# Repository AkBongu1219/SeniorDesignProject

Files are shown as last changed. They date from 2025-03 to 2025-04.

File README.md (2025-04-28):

# Domus Smart Home

## Edge-Controlled Smart Home Ecosystem Integrating Energy Management, Security, and Privacy-Focused Automation

---

## Project Overview

**Domus** is a unified smart home control and security system, designed to overcome the fragmentation in traditional home automation solutions. Built on the Raspberry Pi platform and supported by a network of ESP32-based sensor nodes, Domus integrates:

- Environmental Monitoring (Air Quality, Temperature, Humidity, Pressure)
- Motion Detection with automatic camera activation
- Vision-Based Surveillance (Object Detection & Face Recognition)
- Energy Monitoring and Smart Plug Control
- Edge-Deployed LLM Integration for natural language queries and interaction

The system operates entirely without cloud dependency, ensuring local data ownership, enhanced privacy, and low-latency control. Domus leverages a hardware-software co-design approach, combining industrial IoT components, machine learning models, and robust system architecture for a responsive, secure, and modular smart home experience.

---

## Problem Statement

Current smart home solutions often rely on fragmented, cloud-dependent ecosystems with limited interoperability between security, environmental sensing, and energy control. Domus addresses this gap by offering an all-encompassing, modular smart home ecosystem deployed at the edge. It harnesses state-of-the-art technologies like on-device Large Language Models (LLMs), lightweight computer vision frameworks (MobileNet SSD, dlib), and real-time data processing to ensure:

- Robust Security: Theft detection through face recognition and motion-triggered camera surveillance.
- Energy Awareness: Live and historical energy consumption monitoring with anomaly alerts.
- Seamless Control: A centralized, app-based interface for device management and status queries.
- Privacy and Data Ownership: No cloud dependency; all computation happens locally.

---

## System Architecture

The architecture consists of a central Raspberry Pi 5 node, which communicates with distributed ESP32-based Domus sensor units, a Raspberry Pi 4 vision module, and the Domus iOS mobile application.

**System Diagram Placeholder:**  
*(Insert system architecture diagram here: ./assets/system_architecture.png)*

---

## Current Status

The Domus Smart Home System is fully developed, tested, and available for installation. All hardware and software components are complete. User manual, test plans, and setup guides are provided within the repository to ensure easy deployment by future users or developers.

---

## Future Work / Recommendations

While the Domus Smart Home System is fully functional, several areas offer opportunities for future improvement or extension:

- **Cloud-Optional Remote Access:** Implement an optional secure cloud relay for remote access when away from the local network, while maintaining local-first architecture.
- **Custom Alert Configuration:** Allow users to define custom alert rules and thresholds directly through the mobile app interface.
- **Multi-User Role Management:** Extend app functionality to support multiple user roles (admin, guest, etc.) with customizable permissions.
- **Enhanced LLM Query Handling:** Improve natural language query robustness by expanding prompt engineering techniques and fine-tuning on home automation-specific datasets.
- **Automatic Sensor Calibration:** Integrate a calibration routine for environmental and motion sensors during initial setup or periodic operation.
- **Additional Smart Appliance Integration:** Extend support to other smart plugs, lights, and appliances through MQTT or Home Assistant-compatible APIs.
- **Battery Backup Option for Sensor Nodes:** Add battery backup to ESP32 sensor nodes for continued operation during power outages.

These enhancements would increase flexibility, scalability, and robustness for long-term deployments and broader user scenarios.

---

## Things to Watch Out For

- Device Pairing Requires Manual Wi-Fi Setup: Ensure ESP32 devices are properly configured with Wi-Fi credentials via AP mode before pairing.
- Startup Sequence: Always power on the Raspberry Pi 5 central node before powering up peripheral ESP32 devices to ensure successful check-in.
- Surveillance Module Dependency: The Raspberry Pi 4 must be active for facial recognition and object detection features to work properly.
- Energy Monitoring Limitations: Ensure appliances connected to the Domus Power Plug do not exceed rated load (15A/1800W).
- Wi-Fi Reliability: The system assumes stable Wi-Fi coverage across all device locations.
- AI Camera Positioning: Place the camera near the main entrance or high-traffic zones for effective motion-triggered surveillance.
- LLM Query Limitations: GPT-based natural language queries require structured prompts; misuse or malformed queries may lead to irrelevant responses.
- Sensor Calibration: Initial placement and testing are recommended to avoid false positives from motion or environmental sensors.

---

## Getting Started (Quick-Start Checklist)

1. Hardware Setup:
   - Power on the Raspberry Pi 5 (central node) and Raspberry Pi 4 (vision module).
   - Connect ESP32 sensors (motion, BME688) to wall sockets and ensure they are within Wi-Fi range.
   - Place the AI camera near desired surveillance areas.
   - Connect the Kasa Smart Plug to a power source and the local network.
   - Refer to `README_HARDWARE.md` for detailed instructions.

2. Software Setup:
   - Clone this repository to your local machine or Raspberry Pi:
     ```bash
     git clone https://github.com/AkBongu1219/SeniorDesignProject
     ```
   - For Domus device users: Directly deploy the Domus iOS app by following setup instructions on `README_SOFTWARE.md`.
   - For manual setup, refer to `README_SOFTWARE.md`to setup backend.  
   - Log into the app using Google login.
   - Pair sensors via the "Devices" screen in the app.

3. First Test Run:
   - Confirm device check-ins on the backend dashboard or through the app.
   - Verify live data streams on the app's Home, Energy, and Surveillance screens.
   - Test LLM integration by querying system status via the app's assistant interface.

4. Need Help?
   - Refer to the User Manual (`User_Manual.pdf`) in this repository.
   - For common errors and troubleshooting, see the "Getting Help" section of the User Manual.
   - Contact Team 27 (emails listed below).

---

## Contributors (Team 27)

| Name | Role | Email |
|---|---|---|
| Venkata Sai Sreeram Andra | System Integration, ML Pipelines | vssa8989@bu.edu |
| Anirudh Singh | Backend Development, API Integration| ansingh@bu.edu |
| Vansh Bhatia | Hardware Design, Sensor Integration | vansh@bu.edu |
| Akhil Bongu | Vision Module, Object Detection | akbongu@bu.edu |

---

*End of README.md*

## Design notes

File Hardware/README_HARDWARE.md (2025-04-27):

# Domus Smart Home — Hardware Documentation

**EC464 Senior Design Project**  
**Boston University, Team 27**

---

## 1. Introduction / Overview of Hardware System

The Domus Smart Home system employs a network of hardware components to enable environmental sensing, energy monitoring, and vision-based security. Built on an edge-deployed architecture, the system ensures enhanced privacy and low-latency performance without cloud dependency.

### Key Hardware Components:
- ESP32 Microcontrollers: Motion detection and air quality sensing.
- Raspberry Pi 5: Central control unit.
- Raspberry Pi 4: Dedicated video processing (vision module).
- TP-Link KP115 Smart Plug: Real-time energy tracking and appliance control.
- IMX500 AI-Enabled Camera Module: Object detection and facial recognition.

All devices communicate over a local Wi-Fi network, providing seamless integration and reliable modular deployment.

---

## 2. System Diagram / Hardware Schematic

The system architecture, including sensor nodes, camera module, and smart plug integration, is illustrated below:

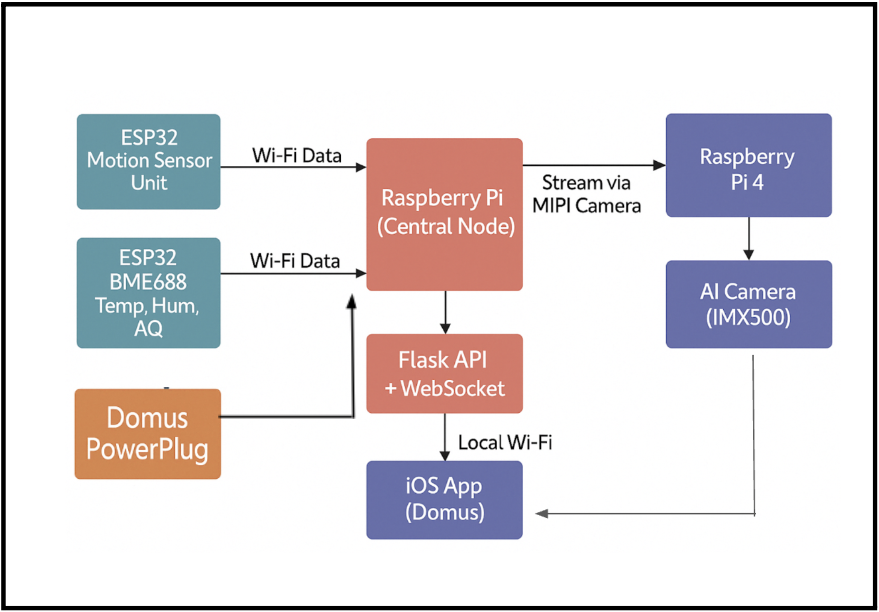
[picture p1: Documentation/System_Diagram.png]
Domus System Hardware Schematic


---

## 3. Photos of Physical Hardware Modules

### Domus Hardware Modules

#### Domus EnvironSensor Module  
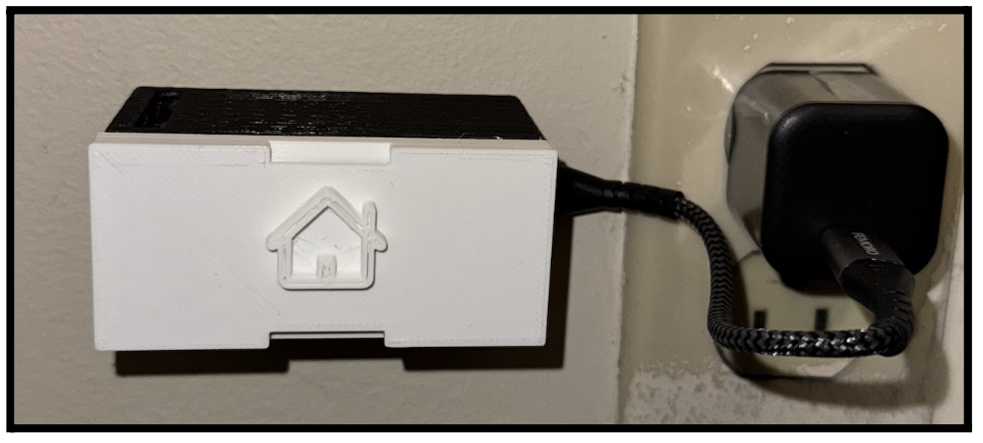
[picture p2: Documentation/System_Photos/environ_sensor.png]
Domus EnvironSensor


#### Domus Vision Module  
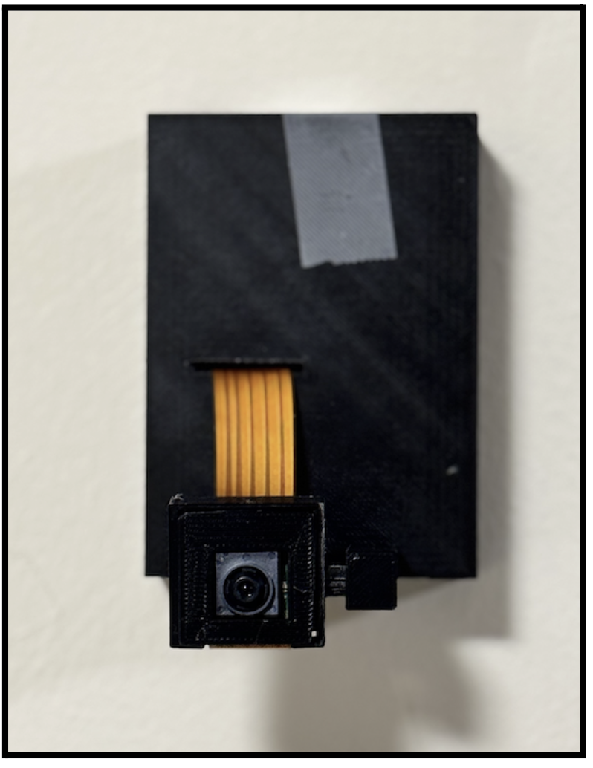
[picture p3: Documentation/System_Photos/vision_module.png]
Domus Vision Module


#### Domus Power Plug  
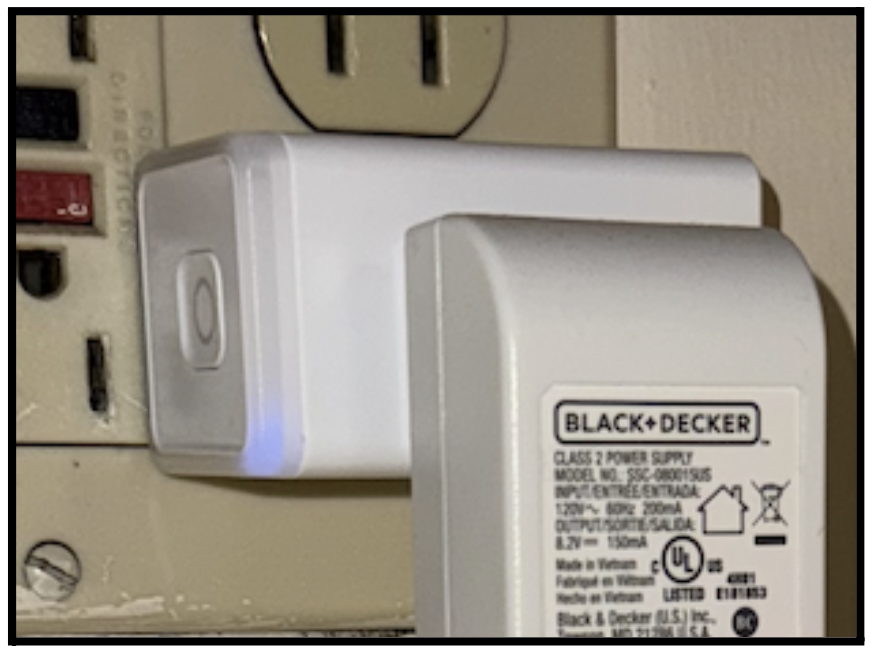
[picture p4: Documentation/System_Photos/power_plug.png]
Domus Power Plug


#### Domus Central Hub (Raspberry Pi 5)  
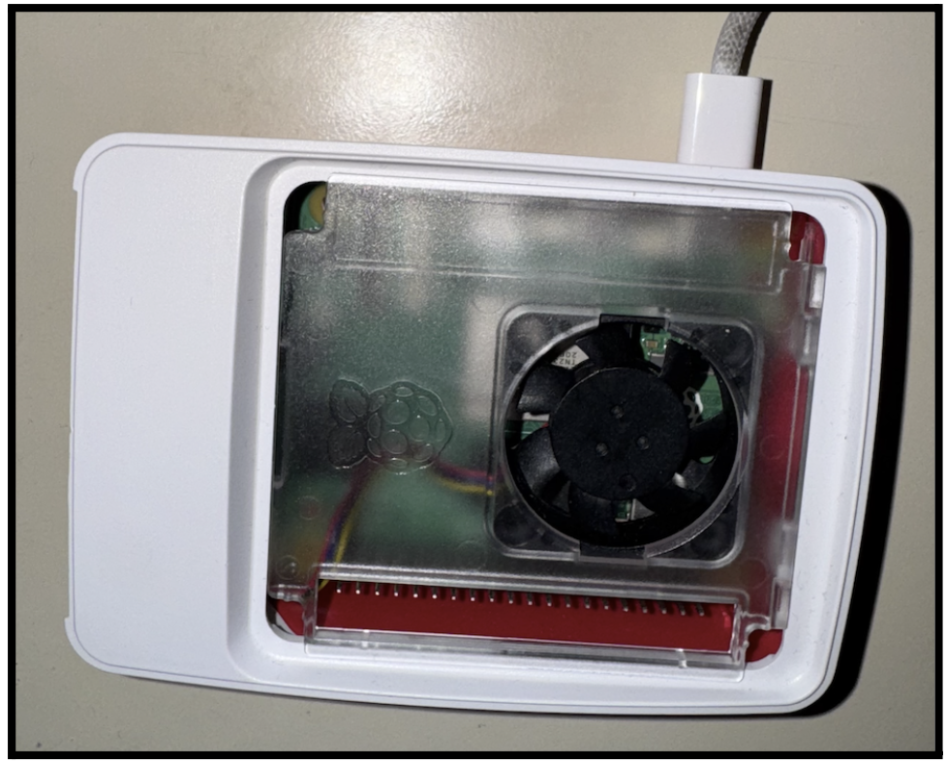
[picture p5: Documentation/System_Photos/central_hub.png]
Domus Central Hub


#### Domus Motion Sensor (HC-SR501)  
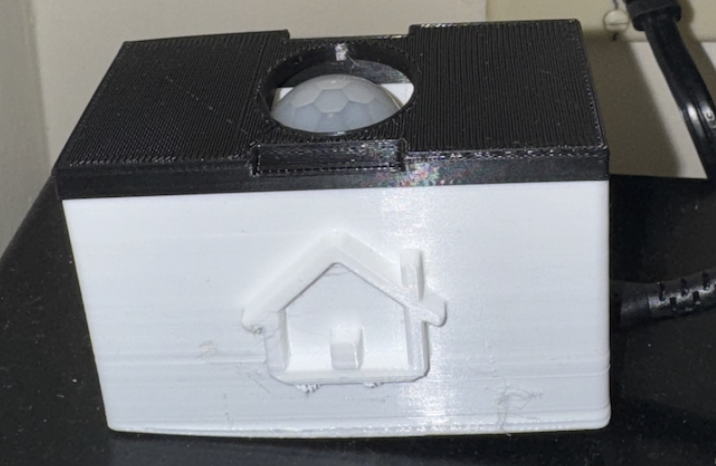
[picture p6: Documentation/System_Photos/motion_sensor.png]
Domus Motion Sensor


---

## 4. Vendor Information Table

| Component | Vendor | Notes |
|---|---|---|
| Raspberry Pi 5 | Amazon | 8GB RAM version |
| Raspberry Pi 4B | Amazon | 4GB RAM, used for camera processing  |
| ESP32 Microcontroller | Amazon | Two units, DevKitC boards |
| BME688 Environmental Sensor | Amazon | Connected to ESP32 |
| HC-SR501 Motion Sensor | Amazon | PIR-based motion detection |
| TP-Link KP115 Smart Plug | Amazon | Energy tracking & appliance control  |
| Raspberry Pi AI Camera (IMX500) | Adafruit | Vision module (IMX500 sensor) |
| Raspberry Pi 5 Case | Amazon | Official Raspberry Pi case |
| USB-C Cables / Adapters | Amazon | Power and data cables |

---

## 5. Technical Specifications (from User Manual)

| Module | Description | Specification |
|---|---|---|
| Domus EnvironSensor | Environmental sensing (BME688 via ESP32) | ±0.5°C temp, ±3% RH, ±1 hPa pressure, AQI from gas resistance |
| Domus MotionSensor | Motion detection (HC-SR501) | 7-meter range, 120° FOV, ~1s latency |
| Domus Vision Module | Object detection & face recognition (IMX500) | MobileNet SSD V2, dlib face matching, ~20 FPS |
| Domus Power Plug | Energy tracking & control (TP-Link KP115) | ±5% accuracy, 15A/1800W max load |
| Domus App Interface | Mobile control and monitoring (React Native iOS) | Google login, live graphs, plug control, alerts |
| Domus Central Hub | Raspberry Pi 5 (Flask server, APIs, SQLite DB) | Quad-core ARM Cortex-A76, 8GB RAM, HTTP + WebSocket APIs |
| Communication System  | Wi-Fi connectivity | IEEE 802.11, HTTP/1.1, WebSocket, mDNS |

---

## 6. Assembly / Setup Instructions

### Hardware Setup Instructions:

1. **Prepare Power Sources:**
   - Use USB-C adapters for Raspberry Pi 5 and Raspberry Pi 4.
   - Plug ESP32 sensor nodes into wall sockets.
   - Ensure TP-Link Smart Plug is connected to a reliable power outlet.

2. **Sensor and Module Placement:**
   - **Motion Sensor:** Near doorways, main hallway.
   - **EnvironSensor:** Away from heat/cooling sources for accurate readings.
   - **Camera Module:** Securely mount facing entry points.

3. **Camera Setup:**
   - Connect the IMX500 AI camera to Raspberry Pi 4 via MIPI interface.
   - Confirm stable attachment and orientation.

4. **Power On Sequence (Important):**
   - Turn on **Raspberry Pi 5 first** (central hub).
   - Then power on Raspberry Pi 4 and ESP32 sensor nodes.
   - Last, activate the Smart Plug.

5. **Initial Device Pairing via App:**
   - Open Domus iOS app (TestFlight deployment).
   - Login with Google.
   - Use the “Devices” screen to discover and pair sensors.
   - Confirm pairing success via status indicators.

---

## 7. Datasheets / References

- [Raspberry Pi 5 Product Brief](https://datasheets.raspberrypi.com/rpi5/raspberry-pi-5-product-brief.pdf)
- [Raspberry Pi 4 Model B Datasheet](https://datasheets.raspberrypi.com/rpi4/raspberry-pi-4-datasheet.pdf)
- [ESP32 Datasheet](https://www.espressif.com/sites/default/files/documentation/esp32_datasheet_en.pdf)
- [BME688 Sensor Datasheet](https://www.bosch-sensortec.com/media/boschsensortec/downloads/datasheets/bst-bme688-ds001.pdf)
- [HC-SR501 Motion Sensor Datasheet](https://www.mpja.com/download/31227sc.pdf)
- [TP-Link KP115 Smart Plug Product Page](https://static.tp-link.com/2020/202010/20201030/KP115%28US%291.0%20%26%201.8_Datasheet.pdf)
- [Sony IMX500 Camera Overview](https://www.sony-semicon.com/en/products/IS/imx500.html)

---

*End of README_HARDWARE.md*

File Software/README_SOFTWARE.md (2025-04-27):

## ✅ Option 1: Easiest Setup (Prebuilt Domus System - Recommended for General Users)

If you have purchased the pre-configured **Domus Smart Home system with Domus-enabled sensors**:

- All hardware components (sensor nodes, vision module, central hub) come **pre-flashed and pre-configured**.
- The backend server and detection models are **already set up on the central Raspberry Pi 5 hub**.
- You do **NOT** need to manually clone the repository or run any backend setup scripts.

---

### 🟢 **Steps to Get Started:**

1. **Clone the Repository Frontend Application:**
   ```bash
   git clone https://github.com/your-repo/domus-smart-home.git
   cd SeniorDesignProject/Software/Frontend/Domus_Application/
   ```

2. **Run the Frontend Setup Script:**
   ```bash
   bash setup_frontend.sh
   ```

   This will:
   - Check for Node.js and npm.
   - Install JavaScript dependencies via `npm install`.
   - Install React Native CLI (if not present).
   - For macOS users: Run `pod install` for iOS dependencies (if using native iOS build).

3. **Open the App in Xcode for iOS Deployment:**
   - Open the `ios/` project folder in Xcode.
   - Connect your iPhone or use the simulator.
   - Build and run the app directly from Xcode.

4. **Pair Your Devices Through the App:**
   - Power on your Domus hub and sensors.
   - Ensure your mobile device is on the same Wi-Fi network.
   - Use the “Devices” screen within the app to discover and pair available Domus sensors.
   - Configure alerts, energy monitoring, and assistant queries directly through the app.

> ⚠️ **Note:** The backend system is already set up on your purchased Domus hardware. You do not need to run backend setup scripts if you are using the pre-configured system.

---

## 🛠️ Option 2: Developer / Manual Setup via GitHub Repository

If you are a developer or builder who wants to manually set up the Domus Smart Home system from source, use the provided backend and frontend setup scripts.

The following instructions explain how to install dependencies, configure the environment, flash sensor nodes, and prepare detection models.

### ✅ Backend Setup Instructions

#### Step 1: Navigate to the Backend Folder
After cloning the repository:
```bash
cd SeniorDesignProject/Software/Backend/
```

#### Step 2: Run the Backend Setup Script
```bash
bash setup.sh
```

The setup script will:
- Check for Python 3.x.
- Create a Python virtual environment (`venv/`).
- Install all dependencies from `requirements.txt`.
- Generate the required folder structure (`logs/`, `db/`, `models/`).
- Run the database setup script (`setup_database.py`).
- Create two helper scripts:
  - `flash_sensors.sh`: For flashing ESP32 sensor nodes.
  - `download_models.sh`: For downloading detection models (currently a placeholder — see below).
- Install Node.js dependencies for the LLM backend (located in `LLM/server.js`).

#### Step 3: Configure Environment Variables
⚠️ **Important:**  
You must configure environment variables for **both the backend and the LLM service**.

1. Backend root:
   ```bash
   cp .env.example .env
   ```
   Fill in:
   ```bash
   OPENAI_API_KEY=your_openai_key_here
   SMART_PLUG_IP=192.168.1.100
   CAMERA_STREAM_IP=192.168.1.200
   ```

2. LLM backend (inside `LLM/` folder):
   ```bash
   cd LLM/
   cp .env.example .env
   ```
   Fill in:
   ```bash
   OPENAI_API_KEY=your_openai_key_here
   ```

> ✅ Both `.env` files must be properly configured for the system to work.

#### Step 4: Add Detection Models
A placeholder script `download_models.sh` is provided inside the `Backend` folder:
```bash
./download_models.sh
```

You must **edit this script** and add the appropriate `wget` or `curl` commands to download your detection models (e.g., `.tflite` files or face recognition encodings). Example:
```bash
wget https://your_model_link.com/model.tflite -O models/model.tflite
```

If you already have the models, you can simply place them manually into the:
```
SeniorDesignProject/Software/Backend/models/
```
folder.

#### Step 5: Flash the ESP32 Sensor Nodes
The setup script also generates `flash_sensors.sh`, which provides flashing commands using `arduino-cli`.

Make sure:
1. You have Arduino CLI installed.
2. Your ESP32 sensor node code (`motion_sensor_ESP32.ino` and `BME688_ESP32.ino`) is located inside:
   ```
   SeniorDesignProject/Software/Backend/ESP32_Code/
   ```

To flash your sensors:
```bash
./flash_sensors.sh
```

> ⚠️ Check that the correct USB port (`/dev/ttyUSB0`) and board name (`esp32:esp32:esp32wrooomda`) are specified in `flash_sensors.sh`.  
> Use `arduino-cli board list` to verify your board and port.

#### Step 6: Activate Your Environment Before Running
Every time you work on the backend, activate your Python environment:
```bash
source venv/bin/activate
```

#### (Optional) Manually Start the LLM Backend
To manually start the LLM backend (if needed for testing or development):
```bash
cd SeniorDesignProject/Software/Backend/LLM
npm start
```
The LLM server listens on port `5051` (configured in `server.js`).

---

### ✅ Frontend Setup Instructions (React Native App)

#### Step 1: Navigate to the Frontend Folder
```bash
cd SeniorDesignProject/Software/Frontend/Domus_Application/
```

#### Step 2: Run the Frontend Setup Script
```bash
bash setup_frontend.sh
```

The frontend setup script will:
- Check for Node.js (version 18 or higher).
- Install JavaScript dependencies from `package.json` using `npm install`.
- Install Expo CLI globally if not already present.
- For macOS users with the iOS folder: automatically run `pod install` to handle CocoaPods dependencies.

#### Step 3: Configure Environment Variables (If Applicable)
If your frontend app uses environment variables, ensure that a `.env` file is created (use `.env.example` if provided).

> ⚠️ **Reminder:** Fill out any required API keys or configuration values in your `.env` file for successful app operation.

#### Step 4: Start the React Native Development Server
```bash
npm start
```
or
```bash
npx react-native start
```

For running on physical devices:
- Use **Expo Go** for quick testing (if using Expo).
- Or build directly via **Xcode (iOS)** or **Android Studio (Android)** if using native builds.

---

---

## ⚙️ Development Environment and Tool Versions

The following tools and versions were used for building and testing the Domus Smart Home system:

### Backend (Python)
- Python: 3.11.x
- Flask: 2.3.2
- Flask-SocketIO: 5.3.4
- Python-SocketIO: 5.9.0
- OpenCV: 4.8.1.78
- dlib: 19.24.2
- face_recognition: 1.3.0
- numpy: 1.24.4
- requests: 2.31.0
- Arduino CLI: 0.34.3 (for ESP32 sensor flashing)

### LLM Backend (Node.js)
- Node.js: 18.x LTS
- npm: 9.x
- express: ^4.18.2
- axios: ^1.5.0
- openai: ^4.0.0
- socket.io: ^4.7.2

### Frontend (React Native)
- React Native CLI: 0.73.x
- Node.js: 18.x LTS
- npm: 9.x
- react-native-vision-camera: as per package.json
- react-native-permissions: as per package.json
- CocoaPods: 1.12.x (for iOS dependency management)

---

> ✅ Note: Users can either purchase the pre-built Domus system (Option 1) or use the provided setup scripts (Option 2). Manual individual module build instructions are not required, as the setup scripts fully handle installation and configuration.

---

---

## 🗺️ Software Module Flow Diagram

The diagram below illustrates the interaction between different software modules within the Domus Smart Home system:

```
                +---------------------+
                |   Domus Mobile App  |
                |  (React Native CLI) |
                +---------------------+
                           |
            (HTTP REST / WebSocket Communication)
                           |
                +---------------------+
                |   Backend Server    |
                |  (Flask + SQLite)   |
                +---------------------+
            |     |      |       |        |
            |     |      |       |        |
+--------+  +--------+  +--------+  +--------+  +--------+
| Motion |  | Environ|  | Vision |  | Smart  |  |  LLM   |
|Sensor  |  |Sensor  |  |Module  |  | Power  |  |Backend |
|(ESP32) |  |(ESP32 +|  |(Obj    |  | Plug   |  |(Node.js|
|        |  | BME688)|  | Detect |  |(KP115) |  |+ OpenAI|
+--------+  +--------+  | +Face  |  +--------+  +--------+
                        | Recog) |
                         +--------+
```

> ⚠️ **Note:** Each module operates independently and communicates through the Backend Server. The LLM Backend queries the Backend for data to generate assistant responses.

---

## 📱 Domus Smart Home App Screenshots

### Device Pairing and Home Dashboard

| Device Pairing | Home Dashboard |
|---|---|
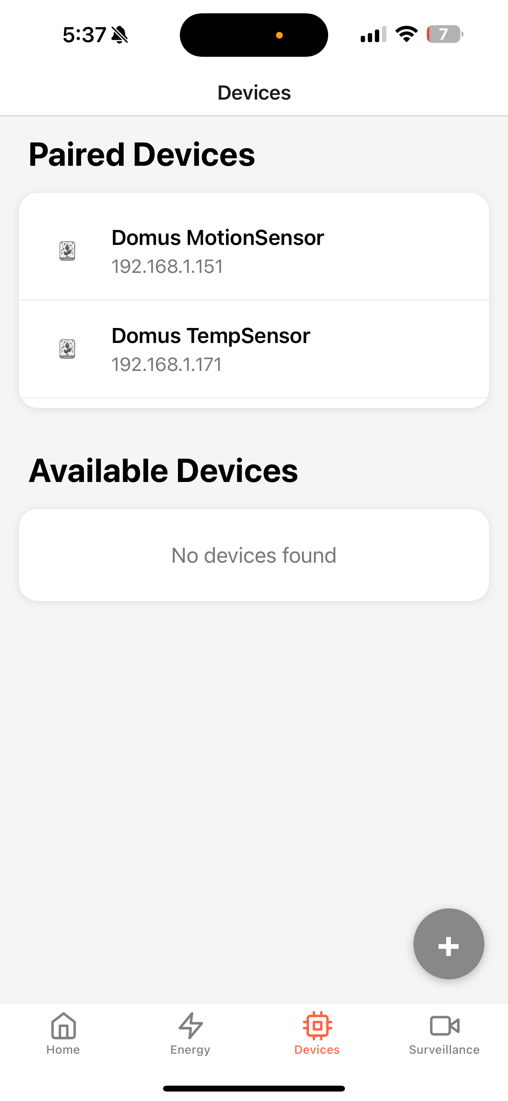
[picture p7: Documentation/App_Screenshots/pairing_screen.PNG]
Pairing Screen
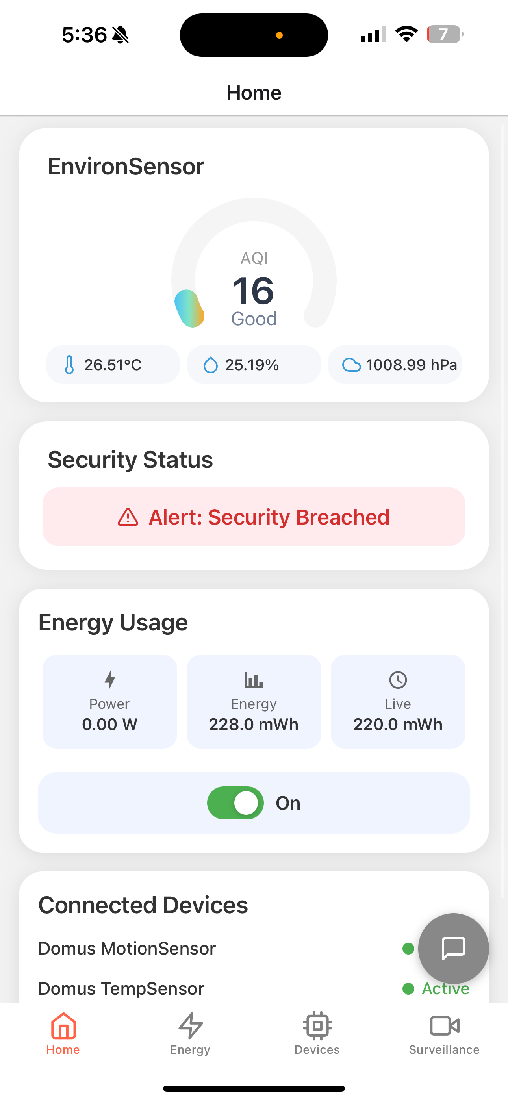
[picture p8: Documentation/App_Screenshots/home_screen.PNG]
Home Screen
|  |  |

### Energy Graphs and Domus Assistant Query

| Energy Graphs | Domus Assistant Query |
|---|---|
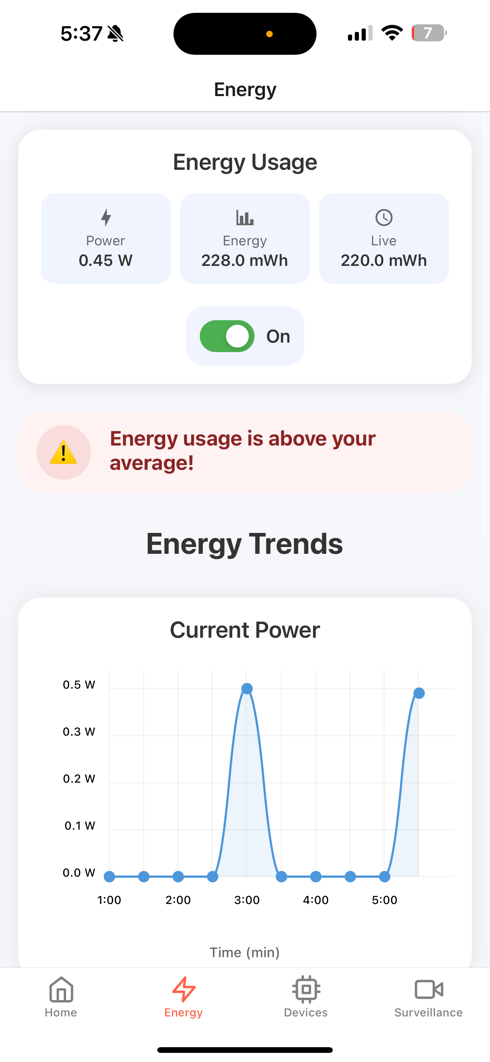
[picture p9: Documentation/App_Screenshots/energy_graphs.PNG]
Energy Graphs
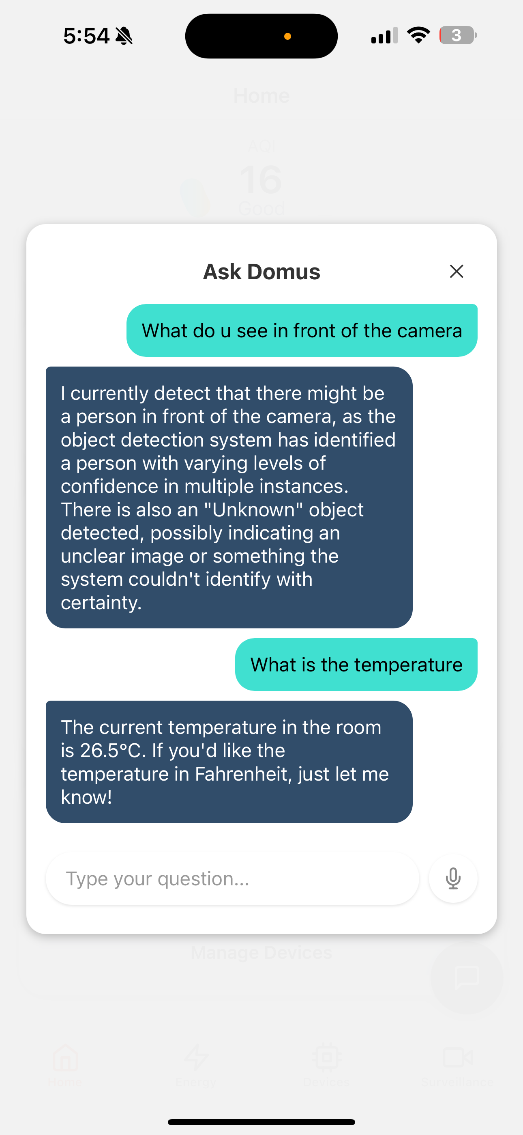
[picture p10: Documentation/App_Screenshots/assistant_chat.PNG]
Assistant Chat
|  |  |

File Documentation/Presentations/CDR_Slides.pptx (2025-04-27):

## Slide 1

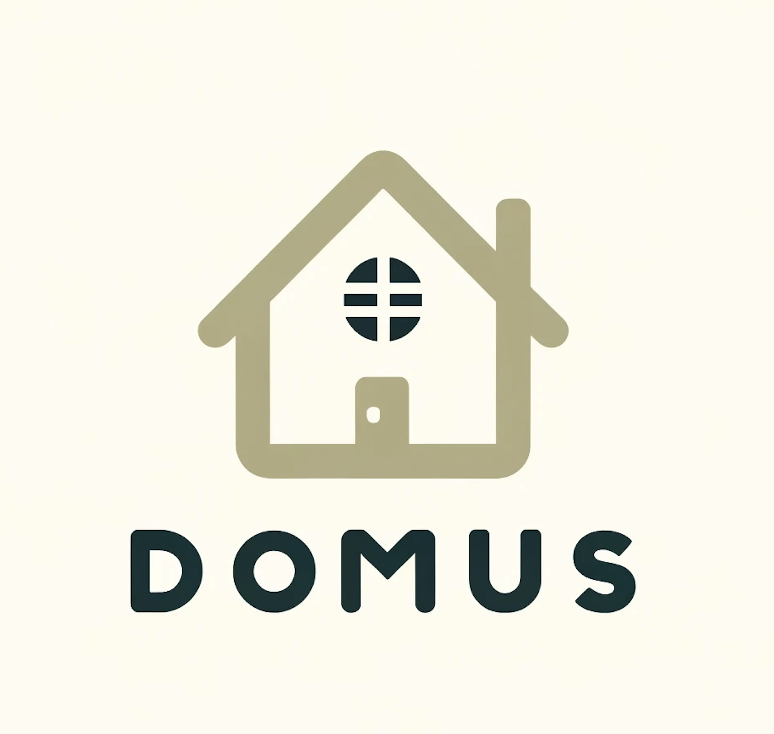
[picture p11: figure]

CDR
Team 27

## Introduction

Sreeram Andra
Computer Engineer: vssa8989@bu.edu
Anirudh Singh
Computer Engineer: ansingh@bu.edu
Vansh Bhatia
Electrical Engineer: vansh@bu.edu
Akhil Bongu
Computer Engineer: akbongu@bu.edu

## Problem Statement

The modern smart home ecosystem is highly fragmented, with separate solutions for security, energy monitoring, and automation. These systems often rely on cloud-based processing, leading to latency, security risks, and lack of seamless integration. Domus solves this by offering a unified, edge-based smart home system that combines multiple functionalities into a single, privacy-focused, real-time solution.

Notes: Ram

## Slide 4

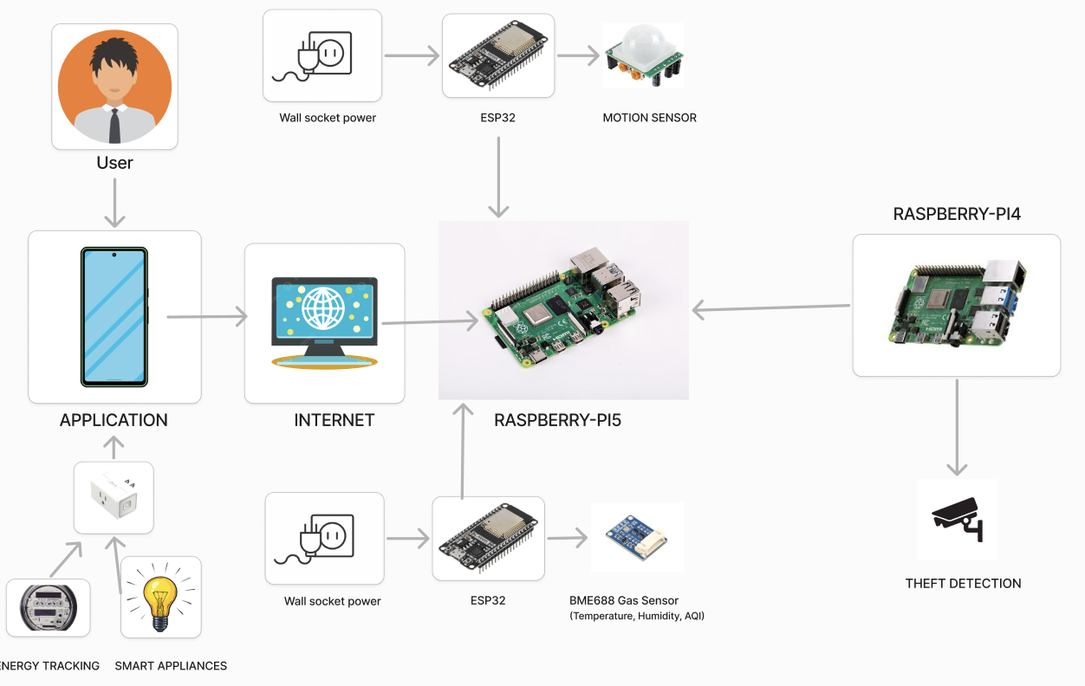
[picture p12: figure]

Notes: Ram

## Design Review/Technologies used

HARDWARE COMPONENT | PURPOSE
Raspberry Pi 5 | Central Microprocessor
Raspberry Pi 4B | Microprocessor for Camera
ESP32 Devkit S1 | Microprocessor for edge Sensors
HCSR 501 | Collects Motion Data
BME 688 | Collects Environmental Conditions Data
Smart Plug (Kasa KP 115) | Measures Energy Consumption
Camera (IMX 500 Raspberry Pi AI) | Collects Video Footage
Edge Modules | Houses Edge Circuits

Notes: Vansh

## Power requirement

Subsystem | Voltage (V) | Current (A) | Total Power consumed per subsystem (W)
Raspberry Pi 5 | 5 | 0.5 | 2.5
Raspberry Pi 4 | 5 | 0.275 | 1.375
ESP32 Devkit S1 (x2) | 3.3 | 0.15 | 0.99
HCSR 501 | 5 | 0.06 | 0.3
BME 688 | 3.3 | 0.015 | 0.0495
Kasa smart plug KP115 | 120 | 0.015 | 1.8
Raspberry pi AI camera | 3.3 | 0.56 | 1.848
Total Estimated Power Consumption | | | 8.8625

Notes: Vansh

## Design Review/Technologies used

SOFTWARE COMPONENT | PURPOSE
C++ Code Files | Collect data from edge sensors
LLM (GPT 3.5 Turbo) | User interactivity
React-Native | UI Interface
Computer Vision Model (dlib + OpenCV) | Facial Recognition
Object Detection Model (MobileNet SSD V2) | Detects objects in camera’s field of view
Activity Recognition Model (MoveNet + LSTM) | Detects human activities in camera’s field of view
SolidWorks | Housing Unit Design
SQLite | Database Storage
WebSocket protocol | Two way real time data communication
Gstreamer protocol | Live streaming of camera footage

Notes: Vansh

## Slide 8

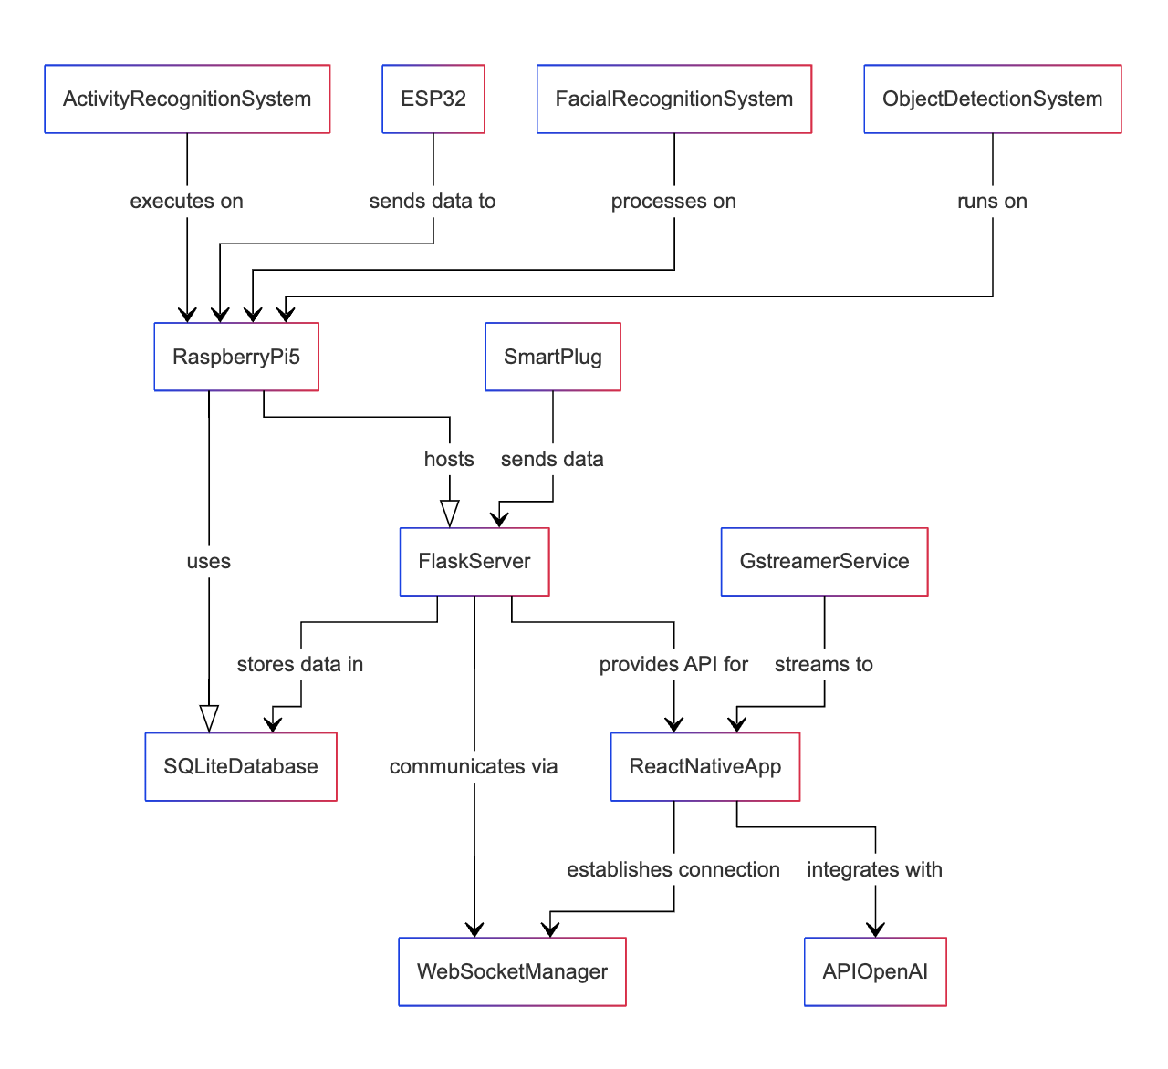
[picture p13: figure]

Software UML Schematic

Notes: Akhil

## Completed Work (Technical Progress)

1. Edge-to-Edge Completion
- All sensors (motion, air quality, temperature) collect data seamlessly
- Real-time communication to Raspberry Pi 5 and app integration
1. Functional LLM Integration
- Smart home assistant understands and responds to queries
1. Energy Visualization
- Graphical energy trends for better monitoring and interactivity
- Live tracking of smart plug energy consumption
1. Fully Functional Application
- Temperature monitoring, intruder detection, and alerts
- Energy data collection and display in the app
1. Object and Face Detection
- Accurate facial and object detection and notification

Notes: Akhil

## Measurable criteria so far

FEATURE | METRIC | OUTCOME
Motion Detection | Detection Accuracy | 100%
Theft Detection | Facial recognition latency | <1 second
Environmental Sensing | Temperature Accuracy | ±1°C
| Other Metric Accuracy | ±2%
Energy Tracking | Toggle latency for devices | <1 second
| Real-time power consumption display | Accurate
Object and Action Detection | Detection Confidence | 90%+ for most objects

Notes: Ram

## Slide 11

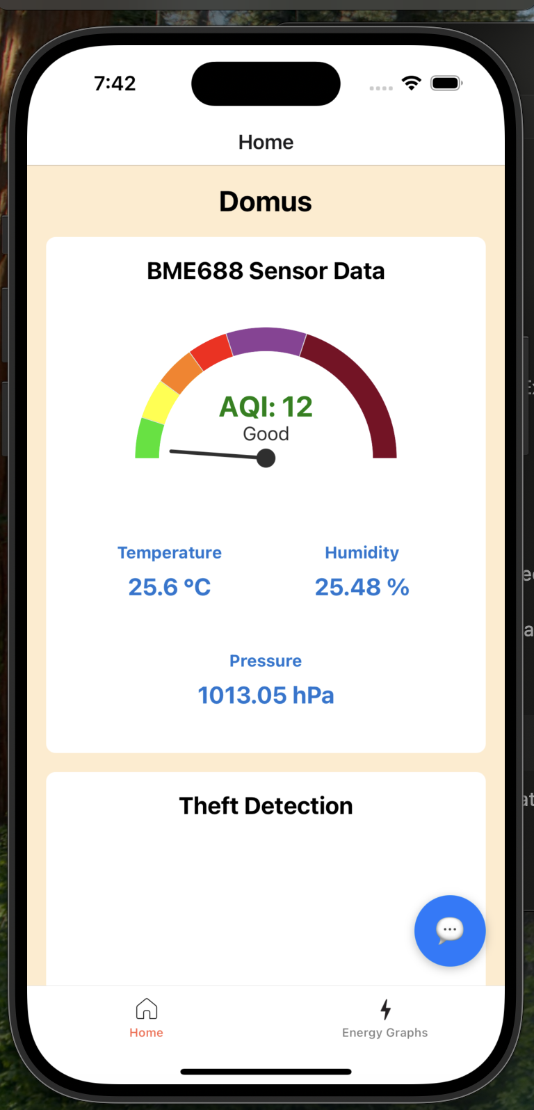
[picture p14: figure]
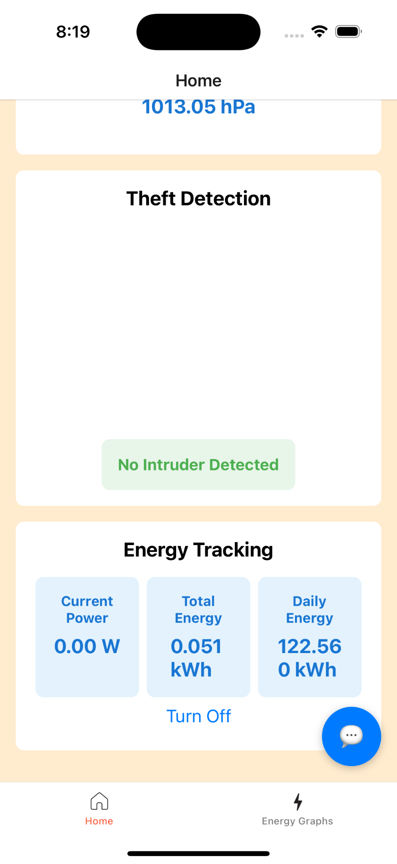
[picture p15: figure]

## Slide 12

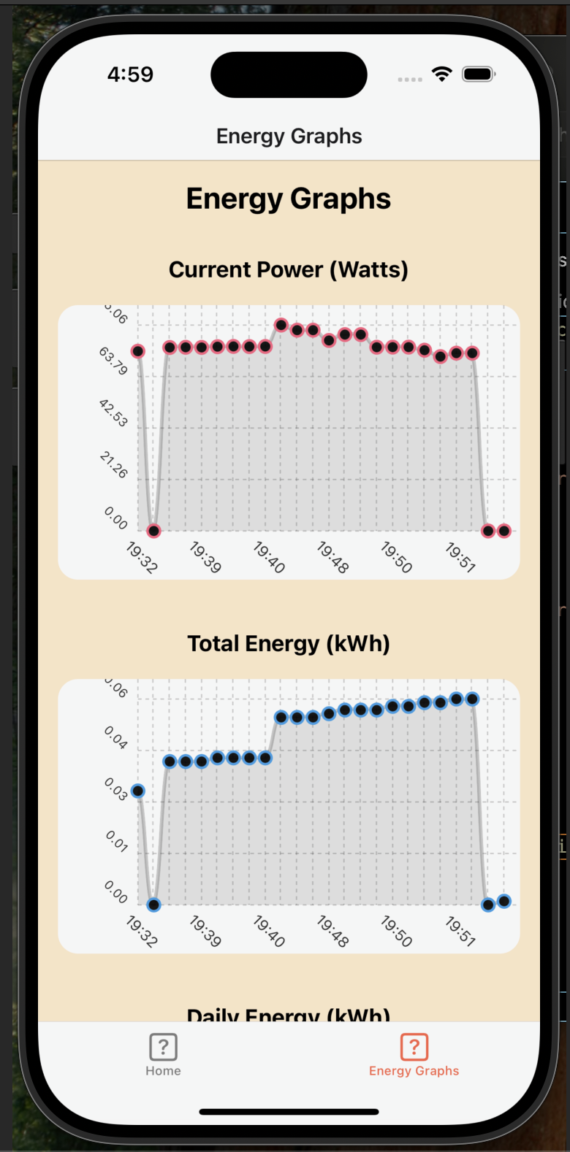
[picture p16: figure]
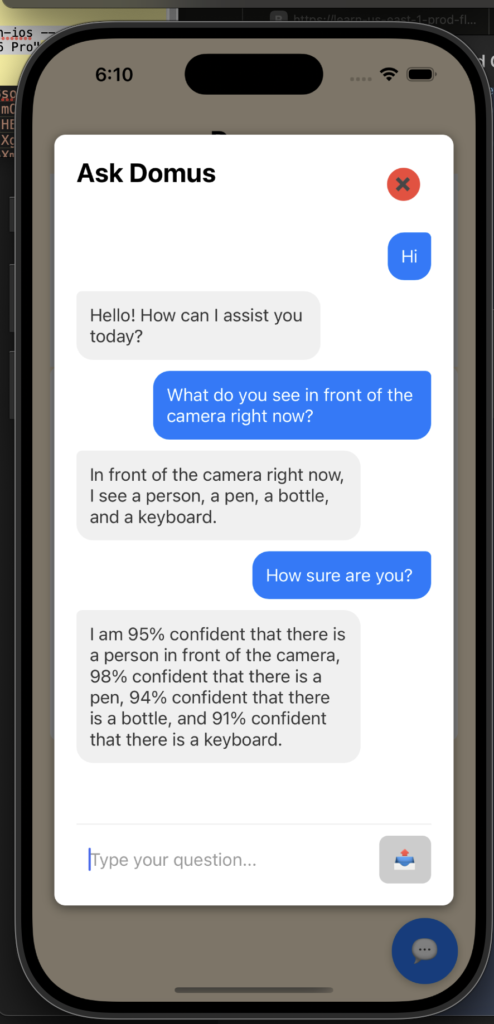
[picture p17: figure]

## Challenges

Challenge | Possible Improvement
Communicating through a single network | Try out BU WiFi with a personal router through a LAN connection
Crafting ergonomic housing units | Optimize design with durable materials and modular components.
Designing an interactive UI | Further iterative development
Streaming quality footage from the camera | Attempt with different streaming protocols/stream to the app directly and run inference on the camera

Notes: Ram

## Work needed for completion

- LLM optimization + voice command integration
- App Design
- Housing Units
- Refinement of Theft Detection System
- Predictive Analysis of Energy Usage
- Reliable Activity Recognition model

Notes: Vansh

## Final Deliverables

- A smart home system, complete with edge sensors and processors within housing units that are easy to place and plug
- An interactive application as a one-stop shop for visualizing and understanding all the data from the smart home system
- A fully functional LLM in the application with which the user can interact with through voice/text

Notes: Akhil

## Timeline

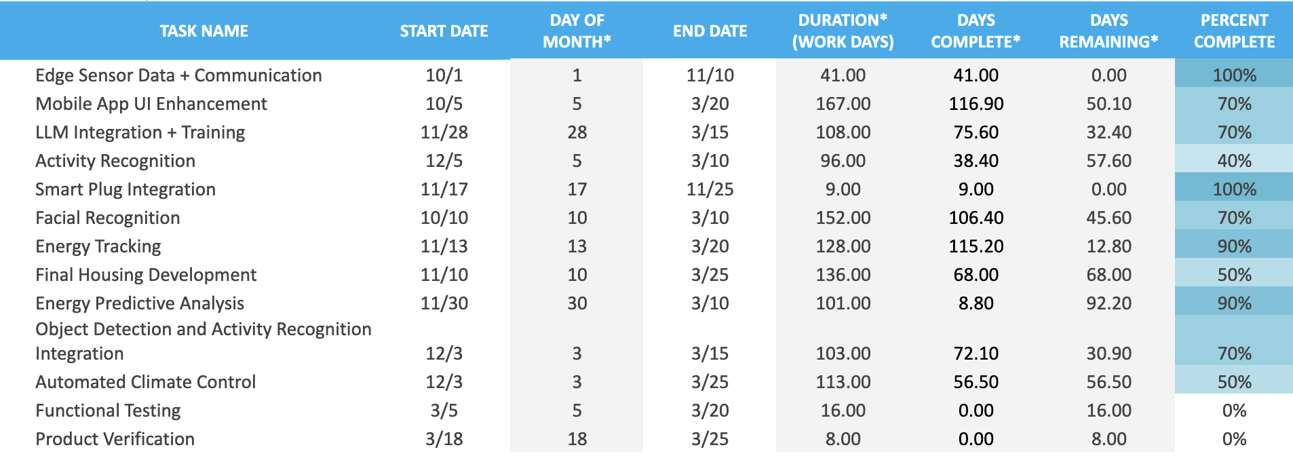
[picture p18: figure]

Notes: Akhil

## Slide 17

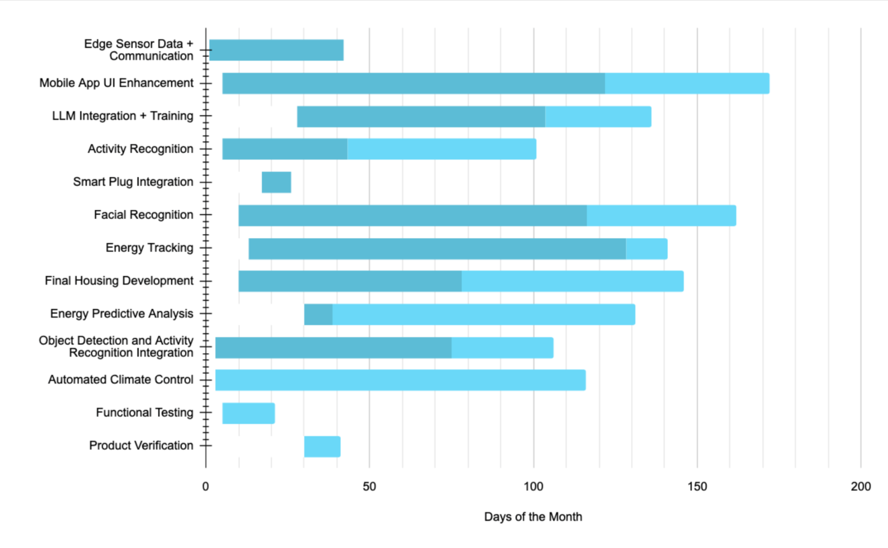
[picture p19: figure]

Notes: Akhil

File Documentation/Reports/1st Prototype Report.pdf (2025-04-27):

# First Prototype Test Report

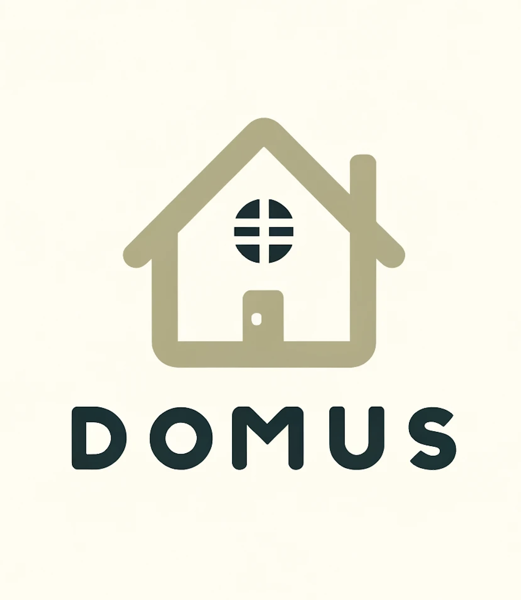
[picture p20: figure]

Team 27
Venkata Sai Sreeram Andra (vssa8989@bu.edu) Anirudh Singh (ansingh@bu.edu) (http://vssa8989@bu.edu) Vansh Bhatia (vansh@bu.edu) Akhil Bongu (akbongu@bu.edu)

# Senior Design

## ENG EC 463

Table of Contents

### 1 Required Materials:

The materials used in this project include a combination of hardware and software components to

facilitate real-time data collection, processing, and mobile application integration for our smart home

system.

1.1: Hardware:

COMPONENT | DETAILS | PURPOSE
Raspberry Pi 5 | 32GB Amazon Basics microSD memory card included | Acts as the central processor for the system
Raspberry Pi 4B | 32GB Amazon Basics microSD memory card included | Serves as an edge processor for the camera module.
ESP32 Microcontrollers | Two microcontrollers with Wi-Fi and Bluetooth capabilities | Collect and transmit data wirelessly
BME688 Sensor | Air quality sensor measuring temperature, humidity, and gas resistance. | Monitors indoor environmental conditions.
Maker Focus Raspberry Camera | 5MP camera with IR LED light and photoresistor. | Provides live video feed for theft detection.
HC-SR501 Motion Sensor | Passive infrared sensor with a wide field of view. | Detects motion for real-time alerts.
XL6009 Voltage Boost Converter | Step-up voltage transformer. | Powers ESP32 boards and sensors.
TP4056 Charging Module | Rechargeable lithium battery charger with protection circuit. | Charges LiPo batteries for edge sensors.
LiPo 3.7V 2000mAh Batteries | Rechargeable lithium-ion batteries. | Powers sensors and microcontrollers.
TP-Link KP115 Smart Plug | Wi-Fi-enabled smart plug. | Tracks energy usage and provides toggle control.

Table 1: Hardware Components Outline

1.2: Software:

TOOL/SCRIPT | DETAILS | PURPOSE
Python Scripts | Flask server and WebSocket. | Relays real-time sensor data to the application.
| GStreamer pipeline. | Streams live video footage.
| dlib + OpenCV. | Collect and transmit data wirelessly
C++ Scripts | Used for low-level data fetching from sensors. | Captures real-time sensor data.
React Native Framework | JavaScript-based mobile app development framework. | Displays sensor data and theft detection outputs.

Table 2: Software Components Outline

### 2 Set Up

2.1: Component Setup

Facial Recognition Model: The Maker Focus 5MP camera was connected to the Raspberry Pi 4 via

the CSI port. The Raspberry Pi 4 was configured as an edge processor to stream video footage to the

Raspberry Pi 5 using a GStreamer pipeline, ensuring low-latency transmission. The facial recognition

system was implemented using OpenCV for image processing and the face_recognition library from

dlib for detecting and distinguishing between authorized and unauthorized individuals. Two persons’

faces from the team were used to train the model by generating a facial encoding.

Environmental Monitoring: The BME688 air quality sensor was connected to an ESP32

microcontroller powered by a rechargeable LiPo battery, and connected to a 5V boost converter to

ensure streamline flow of current. The ESP32 transmitted real-time sensor data (temperature, humidity, gas resistance, and pressure) wirelessly to the Raspberry Pi 5 over the HTTP protocol. Python scripts

on the Raspberry Pi 5 processed the data and displayed it in the React Native app, ensuring accuracy

and consistency with expected sensor readings.

Motion Detection Setup: The HC-SR501 motion sensor was connected to another ESP32

microcontroller powered by a rechargeable LiPo battery. Motion detection events were transmitted

wirelessly to the Raspberry Pi 5 via the HTTP protocol for real-time processing. Motion detection data

was displayed in real-time on the React Native app, verifying system responsiveness.

Energy Monitoring Setup: The TP-Link KP115 smart plug was connected to two home devices (e.g.,

a fan and phone charger). Python scripts on the Raspberry Pi 5 collected power consumption data from

the smart plug via Wi-Fi and sent it to the React Native app for display, through the HTTP protocol.

The app allowed toggling the smart plug on and off in real time.

React Native Application Setup:

- Backend Integration: The React Native app was configured to interact with the Flask server

hosted on the Pi5. HTTP GET requests and WebSocket connections were established for real-

time updates from the sensors and camera feed.

- Mobile App development: The app was built and deployed using npm using an iOS simulator

powered by Xcode.

- UI Setup: The app interface was designed using JavaScript as a simple and user-friendly

interface to provide alerts, display data and control the smart plug.

### 2.2 Pre-testing Setup Procedure

1. Power On the Raspberry Pi 5 and Raspberry Pi 4
a) Connect the Raspberry Pi 5 to a power source using its USB-C cable and ensure the

preloaded microSDXC card is inserted.

b) Connect the Raspberry Pi 4 to a power source using its USB-C cable.
c) Wait for the Raspberry Pi 5 to boot up and verify its connection to the local Wi-Fi network

using terminal commands or the system settings interface.

2. Sensor Validation
a) Ensure that the BME688 (air quality sensor) and HC-SR501 (motion sensor) are powered

through their respective ESP32 edge processors, which are connected to their individual

charging circuits.

b) Execute the pre-installed Python scripts on the Raspberry Pi 5 to validate that sensor data is

being transmitted wirelessly and received correctly.

c) Inspect the console logs for possible transmission errors or lapses in the data relay.
3. React Native App Setup
a) Launch the React Native app on a connected mobile device or emulator.
b) Ensure the app loads successfully to the home screen.
4. Feature Verification: Navigate to each screen within the app to verify functionality of Motion

Sensing, Theft Detection, Energy Tracking.

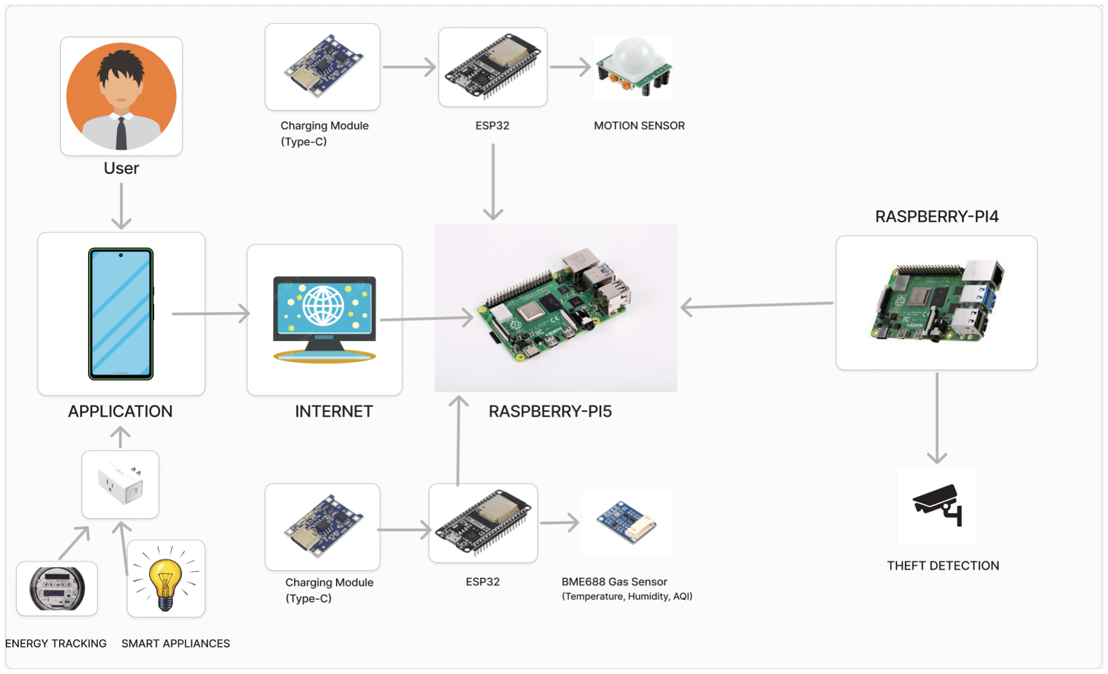
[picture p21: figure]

Figure 1: Illustration of Setup and Process Flow

### 2.3 Testing Procedure:

1. Live Motion Detection: Wave hand in front of the HC-SR501 motion sensor. Verify that

motion detection events are displayed on the React Native app in real time.

2. Face Recognition: Should generate alerts for both authorized and unauthorized personnel in

front of the camera, by displaying authorized and unknown face in the camera’s field of view.

### 3. BME688 Sensor:

- Temperature/Humidity: Should display temperature (in ℃) and humidity (in %).
- Air Quality: Gas resistance should be displayed (in Ohms), which is used as an indicator

for air quality.

- Atmospheric pressure (in hPa) must be displayed on the app.
4. Energy tracking: Video demo of smart plug integration with two home devices (phone charger

and fan). Verify that the React Native app displays real time power consumption data for each

device and test the toggle functionality to switch between on and off.

### 3 Prototype Measurements

1. Motion Detection: The motion sensor successfully detected movements within its field of view

and transmitted data wirelessly to the Raspberry Pi 5. The mobile application displayed these

motion events in real-time with 100% accuracy (Table 1).

2. Facial Detection: The face detection system differentiated between authorized and unauthorized

individuals. The mobile application displayed alerts with facial recognition latency under 1

second, ensuring timely theft detection (Table 1).

3. Environmental Sensing: The BME688 sensor transmitted accurate environmental data

(temperature, humidity, gas resistance, and atmospheric pressure) to the Raspberry Pi 5. These

metrics were displayed in the app with real time updates.

4. Energy Tracking: The smart plug monitored the energy consumption of connected devices and

allowed toggling devices on/off through the app. Power consumption data was displayed in real-

time with toggle latency of less than 1 second (Table 3).

Table 3: Summary of outcomes

### 4 Conclusion

### 4.1 Evaluation

The setup of the Raspberry Pi 5, Raspberry Pi 4 and connected sensors via ESP32 microcontrollers was

consistent with the test plan, ensuring seamless real-time data collection and processing. Each

component operated as intended during testing. The motion sensor detected movements with 100%

accuracy, and the BME688 provided environmental data reliably to the React-Native iOS application

with latency under 1s. Energy consumption data was streamed in real-time, and smart plug toggle

functionality with a latency of under 1 second. Furthermore, the facial detection functionality

distinguishes between an authorized and unauthorized person with 100% accuracy and minimal/zero

latency. Overall, the system demonstrated reliable performance, as shown in the output figures in the

Appendix.

FEATURE | METRIC | OUTCOME
Motion Detection | Detection Accuracy | 100%
Theft Detection | Facial recognition latency | <1 second
Environmental Sensing | Temperature Accuracy | ±1°C
| Humidity Accuracy | ±2%
Energy Tracking | Toggle latency for devices | <1 second
| Real-time power consumption display | Accurate

### 4.2 Problems

We were using Lithium batteries to power our edge sensors. We used charging modules and step-up

voltage transformers to create a rechargeable battery that would constantly power the ESP32

microcontroller that was being used to connect the sensors wirelessly to the Pi5. While this setup works

perfectly and we encountered no problems, the professor suggested that we create a safer circuit that

takes into consideration the power consumption of each individual sensor, possibly without the use of

Lithium Powered batteries for safety concerns. The camera was able to distinguish between the

authorized and unauthorized faces, however, the current computer vision model lacks robustness and is

potentially vulnerable by an image of the authorized user. The camera also displayed high latency due

to poor network connectivity in the testing environment (Senior Design Lab).

### 4.3 Next Steps

- Upgrade camera module for better quality footage and reduce latency of the stream. Redesign the

circuit focusing on safety and find a safer alternative for the LiPo Batteries.

- Train a more advanced computer vision learning model for better facial recognition functionality

and leverage this model to achieve other use cases including object detection and motion detection-

based camera control.

- Integrate the Coral USB Accelerator for better inference speed and efficiency of our AI models.
- Incorporate the LLM for predictive energy usage analysis, and quantitative modeling.
- Upgrade to a more ergonomic housing unit focusing on better aesthetics and usability.

### 5 Appendix

Images of iOS Application (showing output)

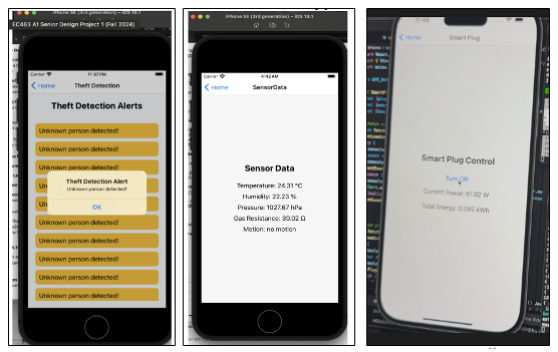
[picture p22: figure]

Video Demonstration (of smart plug functionality):

https://drive.google.com/file/d/1WXRDXypXxjN8U8YxBPOfypv0rjeruogk/view?usp=share_link

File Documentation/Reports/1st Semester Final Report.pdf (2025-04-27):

## Boston University Electrical & Computer Engineering

EC463 Senior Design Project

## First Semester Report

## Domus

Submitted to

Prof. Alan Pisano
Boston University
8 St. Mary’s Street, Boston, MA 02215 apisano@bu.edu

by

Smart Home Control (Team 27) (Domus)

Team Members

Venkata Sai Andra vssa8989@bu.edu
Anirudh Singh ansingh@bu.edu Akhil Bongu akbongu@bu.edu Vansh Bhatia vansh@bu.edu

Submitted: 12/08/2024

Project Proposal | 1

Table of Contents

Table of Contents | 1
Executive Summary | 1
1.0 Introduction | 1
2.0 Concept Development | 4
3.0 System Description | 7
4.0 First Semester Progress | 10
5.0 Technical Plan | 13
6.0 Budget Estimate | 18
Attachments | 20
1.1 Appendix 1 – Engineering Requirements | 20
1.2 Appendix 2 – Gantt Chart. | 21
1.3 Appendix 3 – Other Appendices | 23

Executive Summary
Smart Home Control and Security System Team 27 – Domus

The growing dependence on cloud-based smart home systems has heightened concerns about data privacy and security vulnerabilities. This underscores the need for a solution that ensures real-time control while protecting user information. This project aims to develop a fully operational smart home automation system utilizing edge computing, enabling local data processing to enhance privacy, ensure seamless functionality, and provide secure, real-time control for users. The system will integrate edge-computing technology with IoT-enabled devices, allowing data to be processed on local hardware rather than external servers, supported by secure communication protocols and robust system optimization. This solution uniquely builds on to keep a check of energy consumption, complete control over smart appliances, surveillance as well as multi-device compatibility in a single platform, offering a one stop solution.

Authored by Vansh Bhatia

Team 27 Domus | 12/08/24

### 1.0 Introduction

Modern homeowners face a fragmented and cumbersome smart home experience due to the disparate nature of current solutions. Systems for security, energy management, and automation often operate independently, requiring multiple platforms or apps. Popular market options, like Google Nest or Amazon Alexa, primarily rely on cloud services, creating vulnerabilities in data privacy and increasing the risk of service disruptions. As these systems collect and store vast amounts of user data externally, users are increasingly skeptical about entrusting sensitive information to them. Furthermore, the product offers insights via the Domus application about energy consumption, air quality, temperature, humidity, as well as real-time streaming from surveillance cameras.

Smart home systems have grown in popularity due to the convenience and automation they offer. However, the heavy reliance on cloud-based operations often leads to challenges, including latency, service outages, and potential data breaches. Customers increasingly prioritize solutions that allow them to maintain control over their data and ensure secure, efficient operation. The industry currently lacks a comprehensive, unified solution that can handle automation, security, and energy management while providing robust privacy and real-time performance.

The purpose of this project is to design and develop an integrated smart home automation and security system leveraging edge computing. By processing data locally on user-owned devices rather than transmitting it to external servers, this system aims to provide a one-stop solution addressing automation, real-time control, energy management, and enhanced security. This approach not only addresses privacy concerns but also ensures seamless functionality without reliance on internet connectivity.

Our team’s approach involves creating a robust smart home platform centered on a Raspberry Pi-based central unit and supported by Coral AI boards. The system will utilize ESP32 Microcontrollers connected to local sensors for real-time data processing and control. Key features include:

1. Integration of Edge Computing: This reduces reliance on cloud servers, ensuring data remains private and response times are minimized.
2. IoT-Enabled Devices: The Camera, Smart Plugs and edge sensors communicate via secure protocols such as Wi-Fi, C++ code, WebSocket Protocol and Gstreamer Protocol files, respectively to ensure interoperability.
3. Customizable Mobile Application: A user-friendly interface allows for seamless management of devices, security alerts, and energy monitoring.
4. Local LLM Integration: Pre-trained context given by the user is processed locally, providing intuitive responses without sacrificing privacy.
5. Real-Time Environmental Metrics: Energy consumption, air quality, temperature and humidity tracking are augmented by predictive modeling to empower users with actionable insights.

Highlights and Special Features:

1. Privacy-Centric Design: By avoiding cloud-based data processing, the system minimizes privacy risks while providing offline functionality.
2. Energy Optimization: Advanced analytics provide actionable recommendations to reduce energy consumption and costs.
3. Comprehensive Integration: Combines security, automation, and energy management into one seamless platform.
4. Enhanced Security: Motion detection and theft alerts are processed locally for faster response times and greater reliability.
5. Scalability: Compatible with a wide range of protocols, the system supports up to 30 devices, making it suitable for homes of all sizes.

This project offers a pioneering solution for smart home automation, bridging the gap between user needs and current technological limitations.

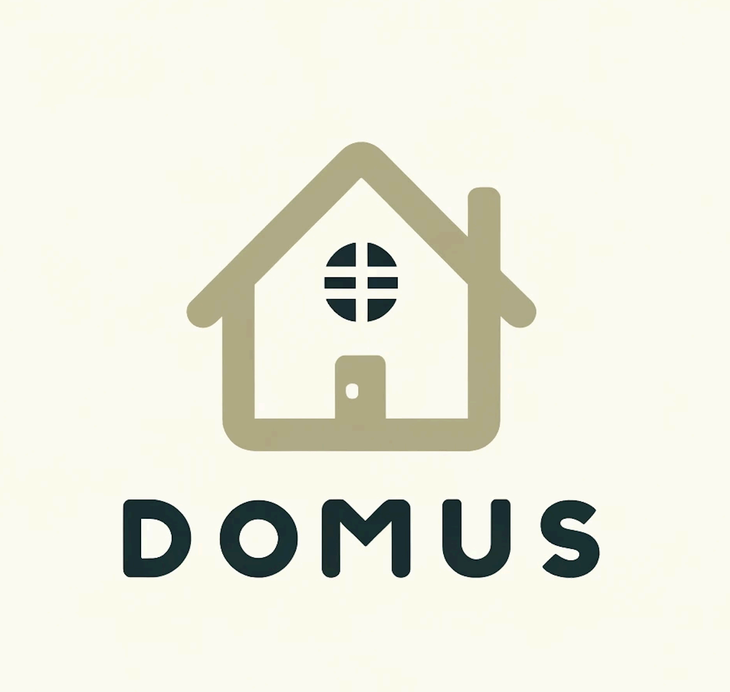
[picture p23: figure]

Figure 1: The DOMUS logo draws its name from the Latin word "Domus," meaning "home"

Authored by Vansh Bhatia

### 2.0 Concept Development

Understanding the Customer’s Problem

The modern homeowner seeks an integrated solution to enhance home automation, ensure security, and minimize energy consumption. Current smart home systems, while popular, often fail to address critical customer concerns such as:

1. Privacy: Heavy reliance on cloud-based processing raises issues of data security and unauthorized access.
2. Latency: Cloud-dependent systems introduce delays in real-time operations, especially in remote or low-connectivity environments.
3. Scalability and Modularity: Existing solutions often lack the flexibility to expand or customize according to specific needs.
4. Lack of streamlined solutions for Surveillance: Current surveillance systems fail to provide reliable, real-time security solutions. Features like motion detection and facial recognition are often inaccurate or delayed, making them inadequate for proactive threat detection and response.

### 5. Lack of Integrated Solutions: Most smart home systems offer fragmented

functionalities, requiring separate devices and apps for energy tracking, environmental monitoring, and security. This lack of a unified system complicates user experience and reduces overall efficiency.

Customers desire a "one-stop" smart home solution that integrates multiple functionalities while ensuring real-time feedback, modularity, and data security. A locally processed, edge-based system addresses these gaps by combining privacy, responsiveness, and adaptability.

Conceptual Approach

To address the above challenges, the proposed Domus Smart Home Control System adopts an edge-based architecture with wireless sensor connectivity to a central hub. The system prioritizes privacy, reliability, and scalability by minimizing cloud dependence and leveraging local processing.

1. Core Features:
- Environmental Monitoring: Integrate the BME688 sensor to provide data on temperature, humidity, and air quality index.
- Motion and Theft Detection: Use HC-SR501 motion sensors and a Raspberry Pi HQ Camera Module to detect movement and unauthorized access, powered by facial recognition algorithms.
- Energy Tracking: Track and analyze energy consumption using the TP-Link Smart Plug via the Kasa API, providing insights into usage patterns and enabling predictive billing.
- User Interaction: Offer a seamless user experience through a React Native mobile application that enables monitoring and control of all functionalities.

2. Engineering Requirements:
- Wireless Sensor Integration: Sensors such as the BME688 and HC-SR501 will communicate via ESP32 microcontrollers to ensure flexibility and modularity.
- Localized Processing: The central Raspberry Pi 5 will handle processing tasks, including facial recognition and environmental data aggregation.
- Energy Efficiency: Smart plugs will ensure minimal energy wastage while supporting API-based tracking for predictive analysis.
- Real-Time Feedback: The system will respond to motion and theft detection alerts in <1 second latency.
3. Innovative Features:
- Edge-Based Architecture: Ensures privacy by processing data locally on the Raspberry Pi 5, eliminating dependence on third-party cloud services.
- Modularity and Scalability: The system can easily integrate additional sensors or new functionalities without major architectural changes.
- AI-Powered Theft Detection: Uses machine learning for face recognition to alert homeowners of unauthorized access attempts.
- AI-Powered Object Detection/Activity Recognition: Uses advanced machine learning to enable the system to identify objects and recognize activities in real-time, enhancing situational awareness
- Adaptive User Interface: A user-friendly mobile app provides real-time system insights, energy analytics, and alerts.
- LLM Model: Enables natural interactions, allowing users to query surveillance, energy, and environmental data for real-time insights, enhancing usability.

Rationale for Chosen Approach

The chosen approach reflects a balance of privacy, performance, and user-centric design. By prioritizing edge computing and modularity, the system meets diverse customer needs while addressing limitations in existing solutions. Localized processing ensures both responsiveness and security, while the wireless architecture allows for scalability and ease of installation.

1. Why Edge-Based Architecture?
- The privacy concerns associated with cloud-based systems are eliminated as all sensitive data (e.g., facial recognition) is processed locally.
- Reduced latency ensures real-time operation, crucial for theft detection and motion-triggered responses.
2. Why Wireless Integration?
- Wireless communication between sensors and the central hub ensures ease of installation, scalability, and mobility.
- ESP32 microcontrollers enable low-power, high-efficiency data transmission.

Alternative Solutions Considered

During the concept development phase, several alternative solutions were evaluated and subsequently rejected due to their limitations:

1. Full Cloud-Based Design:
- Reason for Rejection: Privacy concerns were paramount, as cloud-based systems inherently expose user data to external servers. Additionally, reliance on continuous internet connectivity introduces potential points of failure, particularly in areas with unreliable networks.
- Key Learning: While cloud-based systems excel in remote access, they fail to meet critical user expectations for data security and low-latency operation.
2. Wired Sensor Connections:
- Reason for Rejection: Although wired connections offer stability and reliability, they limit system scalability and are impractical for dynamic home environments. Installation complexity also reduces user accessibility and increases deployment costs.
- Key Learning: Wireless integration is essential for providing flexibility and scalability without compromising functionality.
3. Hybrid Processing Architecture:
- Reason for Rejection: This approach attempted to balance local processing and cloud reliance but introduced unnecessary complexity and redundancy. Latency in cloud-dependent tasks undermined the system's responsiveness.
- Key Learning: Edge-based processing is sufficient for the proposed functionalities, offering a simpler and more effective solution.

Authored by Anirudh Singh

### 3.0 System Description

- Motion Detection
The HC-SR501 motion sensor detects movement within a 5-meter range and transmits data wirelessly to the Raspberry Pi 5 via ESP32 boards, triggering theft detection and activity recognition.
Key Metric: Motion detection latency <1 second.
- Theft Detection
A Raspberry Pi HQ Camera captures video upon motion detection. Facial recognition algorithms on the Raspberry Pi 5 identify unauthorized individuals, while a gyroscope enables dynamic camera movement based on motion detection. Key Metrics: Recognition latency <2 seconds; camera repositioning latency <1 second.
- Activity and Object Recognition
AI models on the Coral USB Accelerator detect activities (e.g., walking, sitting) and objects (e.g., keys, phones). Detected activities and objects are integrated into the Domus Assistant for real-time user feedback.
Key Metrics: Activity recognition accuracy ≥90%; object detection accuracy ≥85%.
- Environmental Monitoring
The BME688 sensor monitors temperature, humidity, and air quality, transmitting updates every 5 seconds via ESP32 boards. Data is displayed on the mobile app in real time.
Key Metrics: Temperature accuracy ±1°C; humidity accuracy ±2%.
- Energy Monitoring
The system tracks energy usage via the TP-Link Kasa Smart Plug and provides predictive energy analysis, displaying trends on the app to help users manage consumption.
Key Metric: Predictive billing accuracy ±10%.
- Mobile Application
Built using React Native, the app serves as the central interface for monitoring and control. It displays live sensor data, theft alerts, and allows interaction with the Domus Assistant.
Key Deliverable: Multi-platform (iOS/Android) app with an intuitive interface.
- Domus Assistant (LLM Integration)
The AI-powered assistant provides natural language responses to queries like “What is the current air quality?” or “What objects are in view?”. It retrieves logs and insights from all subsystems in real time.
Key Metric: Query response time <1 second.

Data Flow

All subsystems transmit data wirelessly to the Raspberry Pi 5 hub, where processing is performed locally to ensure privacy. Processed data is sent to the mobile app for user interaction. Figure 1 illustrates the system architecture and data flow.

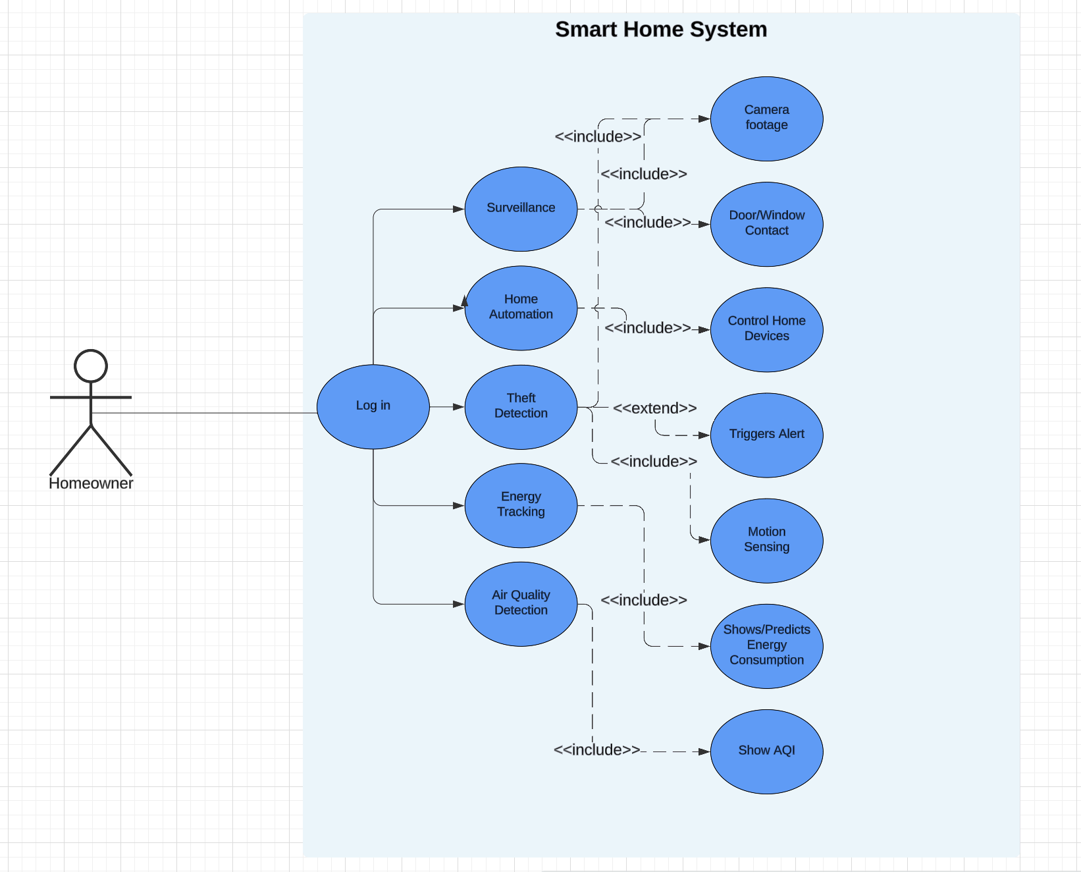
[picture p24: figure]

Figure 2: Workflow Diagram

Conclusion: The Domus Smart Home Control System offers a robust, real-time, and user-centric solution for home automation. By leveraging edge-based processing, wireless communication, and a user-friendly mobile application, the system ensures enhanced privacy, efficiency, and scalability. Its modular design allows for future expansion, making it a versatile and forward-looking solution for modern smart homes.

Sample Images of preliminary Mobile Application User Interface

Home Screen: | Ask Domus: | Splash Screen:


Figure 3: Images of Application


Pseudocode for the system:


Authored by Anirudh Singh

### 4.0 First Semester Progress


Figure 4: High-level Diagram of Prototype

At the end of the Fall 2024 semester, we constructed a functional prototype that integrated several parts of our final project objective. Listed below is the progress that we have made with our project over the Fall 2024 semester:

1. Motion Detection
- The HC-SR501 motion sensor was calibrated to detect movement within a 5-meter range.
- Data is transmitted wirelessly to the Raspberry Pi 5 via ESP32 boards, triggering the theft detection system.
- Key Result: Initial testing confirmed a detection latency of <1 second, with a 98% success rate in identifying motion during controlled experiments.
2. Facial Recognition
- A facial recognition model was developed and trained using OpenCV and the face_recognition library from dlib.
- The model was integrated with the camera subsystem to differentiate authorized and unauthorized faces, sending alerts to the mobile app upon detection.
- Key Result: The system achieved 92% accuracy in identifying faces under ideal lighting conditions, with real-time processing latency of <2 seconds.

3. Environmental Monitoring
- The BME688 sensor was configured to provide real-time readings of temperature, humidity, and air quality.
- Data updates are sent to the Raspberry Pi 5 every 5 seconds via ESP32 boards and displayed on the mobile app.
- Key Result: Sensor accuracy was verified, achieving temperature accuracy of ±1°C and humidity accuracy of ±2% during controlled testing.
4. Energy Monitoring
- The TP-Link Kasa Smart Plug was calibrated to track energy usage and display consumption data on the mobile app.
- Predictive energy analysis functionality is under development, with initial integration of usage logs into the system.
- Key Result: Energy consumption readings were accurate.
5. Activity Recognition (In Progress)
- Preliminary work was conducted on integrating an AI-based activity recognition model using the Coral USB Accelerator.
- The model is currently being trained to identify basic activities such as walking and sitting. Integration with the Domus Assistant and the mobile app is ongoing.
- Key Result: Approximately 10% of the activity recognition system has been implemented, with initial model tests yielding an accuracy of 85% on benchmark datasets.
6. Mobile Application Features
- A preliminary React Native app was developed to serve as the central dashboard for the system.
- Features include real-time data visualization for environmental monitoring, theft alerts, and energy usage tracking.
- Key Result: The app successfully displayed real-time data with <2 seconds latency and allowed seamless navigation between core functionalities.
7. SQL Database Integration
- A SQLite database was integrated into the system for storing sensor logs and event data locally on the Raspberry Pi 5.
- This database enables the system to maintain historical data, supporting features like predictive analytics and detailed user reports.
- Key Result: The database successfully logged sensor data for up to 24 hours during initial tests, with retrieval times of <1 second for queries.
8. LLM Integration
- A foundational version of the Domus Assistant was implemented using GPT-3.5 Turbo.
- The LLM supports basic natural language queries.
- Key Result: User queries were answered within <1 second during initial tests, with 90% accuracy for basic questions.

Table 1: Prototype Metrics

Motion Detection:

- Achieved a 100% detection accuracy, ensuring reliable detection of movement within the prototype’s range (0 - 5 meters)
Theft Detection:
- Optimized the facial recognition system with a latency of less than 1 second, enabling swift identification and alert generation.

Environmental Sensing:

- Temperature Accuracy: Achieved a precision of ±1°C, ensuring dependable temperature monitoring.
- Humidity Accuracy: Maintained an accuracy of ±2%, providing reliable environmental data.

Both temperature and humidity readings were cross referenced with a indoor hygrometer

Energy Tracking:

- Toggle Latency: Enabled device toggling with a latency of less than 1 second, supporting seamless control.
- Power Consumption Display: Provided accurate real-time power consumption readings, facilitating effective energy monitoring.

Authored by Akhil Bongu

FEATURE | METRIC | OUTCOME
Motion Detection | Detection Accuracy | 100%
Theft Detection | Facial recognition latency | <1 second
Environmental Sensing | Temperature Accuracy | ±1°C
| Humidity Accuracy | ±2%
Energy Tracking | Toggle latency for devices | <1 second
| Real-time power consumption display | Accurate

### 5.0 Technical Plan

The Technical Plan outlines the tasks and milestones to be achieved in the upcoming semester, focusing on the completion of the Domus Smart Home Control System. Each task is clearly described with assigned responsibilities, measurable deliverables, and deadlines. The tasks aim to integrate advanced features such as object detection, activity recognition, predictive energy analysis, and enhanced LLM capabilities, culminating in a fully functional system.

Task 1: Object Detection Setup with MobileNet SSD (in progress)

- Description: The MobileNet SSD object detection model shall be deployed using the Coral USB Accelerator. A prebuilt Docker container containing all necessary dependencies, such as TensorFlow Lite and Edge TPU runtime, will be identified and utilized to ensure compatibility. The object detection system will be configured to recognize common household objects such as keys, phones, and bottles.
- Steps:
1. Prebuilt Docker images will be researched, tested, and validated for compatibility.
2. An object detection pipeline will be set up using the Coral USB Accelerator on the Raspberry Pi.
3. Detection accuracy across 10 object categories under varying lighting conditions will be tested.
- Metrics: The system shall achieve a detection accuracy of at least 85% for household objects with an inference latency of <50 milliseconds.
- Lead: Venkata Sai Andra
- Assisting: Akhil Bongu, Anirudh Singh, Vansh Bhatia
- Deliverable: A fully configured object detection system integrated with the Domus Assistant for responding to user queries about detected objects.
- Deadline: February 15, 2025.

Task 2: Activity Recognition Integration

- Description: An activity recognition system using an open-source model such as MoveNet or OpenPose will be implemented. The Coral USB Accelerator will be used to optimize inference performance. Activities like walking, sitting, and waving will be recognized, enabling interaction tracking.
- Steps:
1. Suitable open-source models for activity recognition will be researched and selected.
2. The chosen model will be trained and tested on benchmark datasets such as MS COCO or HMDB51.
3. The model will be deployed on the Coral USB Accelerator and fine-tuned for real-time performance.

- Metrics: The system shall recognize five predefined activities with an accuracy of 90% in test scenarios, maintaining inference latency <100 milliseconds.
- Lead: Venkata Sai Andra
- Assisting: Anirudh Singh, Akhil Bongu, Vansh Bhatia
- Deliverable: A functional activity recognition system integrated with the Domus Assistant and user alerts.
- Deadline: March 1, 2025.

Task 3: Motion-Triggered Camera Streaming

- Description: The motion sensors will be integrated with the camera to trigger live streaming upon detecting movement. The WebSocket protocol will be employed to ensure real-time communication and low latency.
- Steps:
1. The motion sensors (e.g., HC-SR501) will be configured to send alerts to the Raspberry Pi.
2. The camera will be programmed to begin streaming upon receiving motion sensor alerts.
3. The system’s responsiveness will be tested in various room layouts.
- Metrics: The latency between motion detection and camera activation shall remain <1 second.
- Lead: Akhil Bongu
- Assisting: Venkata Sai Andra, Anirudh Singh, Vansh Bhatia
- Deliverable: A motion-triggered live streaming system with real-time alerts.
- Deadline: February 20, 2025.

Task 4: Theft Detection System

- Description: The theft detection functionality shall be enhanced by integrating facial recognition with dynamic camera movement. A gyroscope will be employed to enable the camera to reposition itself based on motion sensor feedback.
- Steps:
1. A gyroscope-controlled pan/tilt mechanism will be implemented to adjust the camera.
2. The facial recognition model will be optimized to handle multiple faces and low-light conditions.
3. Stress tests will be conducted by simulating unauthorized entry scenarios.
- Metrics: The system shall detect and identify faces within 2 seconds, with camera repositioning completed in <1 second.
- Lead: Akhil Bongu
- Assisting: Venkata Sai Andra, Anirudh Singh, Vansh Bhatia
- Deliverable: A theft detection system combining facial recognition and dynamic camera movement.
- Deadline: March 15, 2025.

Task 5: User Facial Data Training

- Description: A feature will be developed to allow users to train the system with their own facial data via the mobile app. A secure mechanism for data storage and real-time updates to the facial recognition database will be implemented.
- Steps:
1. An intuitive user interface for uploading and managing facial data will be created.
2. The system will be programmed to dynamically update the facial recognition database with new inputs.
3. Data encryption will be implemented to ensure secure storage and transmission.
- Metrics: Users shall successfully train the system with new facial data within 30 minutes, with zero data breaches during tests.
- Lead: Vansh Bhatia
- Assisting: Anirudh Singh, Akhil Bongu, Venkata Sai Andra
- Deliverable: A secure and user-friendly facial data training feature in the app.
- Deadline: February 28, 2025.

Task 6: Surveillance-LLM Integration

- Description: Surveillance features, including object detection, activity recognition, and theft detection, will be integrated with the LLM. Users will query the Domus Assistant for real-time logs and insights on detected events.
- Steps:
1. APIs to fetch logs from the surveillance systems will be developed.
2. Prompts for the LLM will be designed to generate concise and accurate responses.
3. The system will be tested under high workload scenarios to ensure performance.
- Metrics: The system shall respond to user queries within 1 second, achieving a >95% accuracy rate in summarizing events.
- Lead: Anirudh Singh
- Assisting: Venkata Sai Andra, Akhil Bongu, Vansh Bhatia
- Deliverable: An integrated LLM system providing real-time surveillance logs.
- Deadline: March 30, 2025.

Task 7: Voice Feedback for LLM

- Description: Voice feedback capabilities will be implemented for the LLM using lightweight text-to-speech (TTS) models such as Google TTS or eSpeak. Users will interact with the Domus Assistant through voice commands and receive verbal responses.
- Steps:
1. Suitable TTS models for Raspberry Pi compatibility will be identified and tested.
2. The TTS system will be integrated with the Domus Assistant.

3. User testing will be conducted to validate speech clarity and latency.
- Metrics: Voice responses shall be generated within 2 seconds, with >90% intelligibility in user tests.
- Lead: Anirudh Singh
- Assisting: Venkata Sai Andra, Akhil Bongu, Vansh Bhatia
- Deliverable: A voice-enabled Domus Assistant.
- Deadline: April 15, 2025.

Task 8: Final Housing Units

- Description: Ergonomic and aesthetically pleasing housing units for all hardware components will be designed and produced using SolidWorks. Focus will be placed on branding, durability, and usability.
- Steps:
1. CAD models for housing units will be designed and iterated upon.
2. Components will be tested for durability through drop tests.
3. Final designs will be evaluated for aesthetics and ergonomic functionality.
- Metrics: Housing units shall withstand drop tests from 1 meter and pass usability evaluations.
- Lead: Vansh Bhatia
- Assisting:Venkata Sai Andra, Anirudh Singh, Akhil Bongu
- Deliverable: Finalized, branded housing units.
- Deadline: March 20, 2025.

Task 9: Finalizing Power Sources

- Description: Evaluate and select batteries and power delivery methods prioritizing safety ratings, efficiency, and compatibility.
- Steps:
1. Research and test batteries for runtime, thermal stability (≤10°C rise), load capacity (~485.86 Wh/day), and portability
2. Assess USB-C PD for Raspberry Pi 5 and centralized charging for sensors.
3. Finalize the safest and most efficient option based on testing.
- Metrics: ≥24-hour runtime, Safety certifications, stable operation under load.
- Lead: All
- Assisting: All
- Deliverable: Deliverable: Final power source selection and circuitry
- Deadline: February 20, 2025.

Task 9: Predictive Energy Analysis

- Description: A predictive energy analysis model shall be developed to estimate electricity usage and billing based on historical data from KP115 plugs. Results will be displayed on the app’s energy monitoring screen.
- Steps:
1. Energy usage data over 30 days will be gathered and preprocessed.
2. A regression-based predictive model will be built and tested.

3. Predictions will be integrated into the app for user access.
- Metrics: Predictions shall achieve an accuracy of ±5% compared to actual usage in test cases.
- Lead: Venkata Sai Andra
- Assisting: Akhil Bongu, Anirudh Singh, Vansh Bhatia
- Deliverable: Predictive energy analysis integrated into the app.
- Deadline: March 25, 2025.

Task 10: Automated Climate Control (Tentative)

- Description: The “Smart Comfort Control” feature shall be implemented to activate heating devices when the temperature falls below a user-defined threshold.
- Steps:
1. A threshold-setting interface will be developed in the app.
2. The system will be programmed to activate heating devices upon threshold breach.
3. Performance will be validated under varying environmental conditions.
- Metrics: Heating activation shall occur within 5 seconds of a threshold breach with 100% reliability.
- Lead: Anirudh Singh
- Assisting: Venkata Sai Andra, Akhil Bongu, Vansh Bhatia
- Deliverable: A fully functional Smart Comfort Control system.
- Deadline: March 10, 2025.

Task 11: Full System Testing

- Description: Comprehensive functional and stress testing shall be conducted for all components, simulating real-world conditions. Results will be documented, and any failures will be addressed iteratively.
- Steps:
1. Comprehensive test cases will be developed for each feature.
2. Iterative tests will be conducted to ensure stability and reliability.
3. Results will be documented and used to refine system performance.
- Metrics: All features shall achieve ≥95% reliability in end-to-end testing.
- Lead: All
- Assisting: All
- Deliverable: A final test report documenting successful system functionality.
- Deadline: April 20, 2025.

Authored by Venkata Sai Andra

### 6.0 Budget Estimate

Item | Description | Total Cost
1 | Raspberry Pi 5 | $92.99
2 | DHT22 | $11.80
3 | IR Motion Sensor | $9.49
4 | MakerFocus Camera | $22.99
5 | BME688 Sensor | $28.79
6 | Raspberry PI case | $14.98
7 | ESP32 | $16.69
8 | Coral USB Accelerator | $73.99
9 | Voltage Booster | $12.99
10 | Charging Module | $9.99
12 | Smart Plugs | $10.00
13 | Raspberry Pi 4 | $61.29
14 | Raspberry Pi HQ Camera | $74.99
Total Spent = $440.98
Remaining = $309.02 (Departmental Budget)

Table 2: Budget
Budget Narrative
1. Major Budget Items:
- The Raspberry Pi 5 and Coral USB Accelerator represent the largest expenditures, accounting for 42% of the total budget. These components are vital for system processing and machine learning tasks, making their inclusion necessary.
2. Sources of Components:
- All components are sourced from Amazon, a reliable vendor known for competitive pricing. This ensures consistency and availability of parts.
- The project relies on standard off-the-shelf components to keep costs manageable and ensure easy replacements if necessary.
3. Budget Constraints:
- With a total budget of $1,000 and a department allowance of $750, the project remains well within limits, leaving $560 unspent overall and $309 within the department allowance.
- This surplus provides flexibility to address unforeseen expenses or include additional components if required.

Authored by Akhil Bongu

Attachments

### 1.1 Appendix 1 – Engineering Requirements

Team #27 | Team Name: Smart Home Control and Security System
Requirement | Value, Range, Tolerance, Units
Modular Sensor Integration | Wireless Communication using ESP32 microcontrollers, each capable of supporting connections of up to 5 sensors; communication range approx > 10 m
Data Processing and Privacy | Localized edge computing on Raspberry Pi 5, ensuring real-time processing with latency ≤ 100ms and no reliance on cloud services.
Motion Detection | Detection range: 0–5m with response time ≤ 1 second.
Theft Detection | Facial recognition accuracy ≥ 90%, response time ≤ 1 second for alerts.
Environmental Monitoring | Temperature: ±1°C, Humidity: ±2%, AQI accuracy ±2%. Data update frequency ≤ 5 seconds.
Energy Tracking | Real-time energy tracking with usage accuracy ±0.01%. Data updated every 2 seconds.
Integration with the Mobile Application | React Native app displaying sensor data, theft detection alerts, and energy monitoring with data refresh rate ≤ 2 seconds.
Power Efficiency | ESP32 boards powered via Type-C charging modules. Battery life ≥ 24 hours with power consumption ≤ 5W per module.
Scalability | Scalable architecture allows integration of at least two additional sensors or modules without significant reconfiguration.
System Performance | End-to-end system reliability ≥ 95%, including seamless communication between sensors, the Raspberry Pi 5, and the mobile application.

Table 3: Engineering Requirements

1.2 Appendix 2 – Gantt Chart.

TASK NAME | START DATE | DAY OF MONTH* | END DATE | DURATION* (WORK DAYS) | DAYS COMPLETE* | DAYS REMAINING* | PERCENT COMPLETE
Edge Sensor Data + Communication | 10/1 | 1 | 11/10 | 41.00 | 41.00 | 0.00 | 100%
Mobile App UI Enhancement | 10/5 | 5 | 3/20 | 167.00 | 50.10 | 116.90 | 30%
LLM Integration + Training | 11/28 | 28 | 2/15 | 80.00 | 32.00 | 48.00 | 40%
Activity Recognition | 12/5 | 5 | 2/10 | 68.00 | 6.80 | 61.20 | 10%
Smart Plug Integration | 11/17 | 17 | 11/25 | 9.00 | 9.00 | 0.00 | 100%
Facial Recognition | 10/10 | 10 | 3/15 | 157.00 | 78.50 | 78.50 | 50%
Energy Tracking | 11/13 | 13 | 1/30 | 79.00 | 55.30 | 23.70 | 70%
Final Housing Development | 11/10 | 10 | 3/20 | 131.00 | 65.50 | 65.50 | 50%
Energy Predictive Analysis | 11/30 | 30 | 3/25 | 116.00 | 8.80 | 107.20 | 10%
Object Detection and Activity Recognition Integration | 12/3 | 3 | 2/15 | 75.00 | 15.00 | 60.00 | 20%
Automated Climate Control | 12/3 | 3 | 3/10 | 98.00 | 0.00 | 98.00 | 10%
Functional Testing | 3/5 | 5 | 3/20 | 16.00 | 0.00 | 16.00 | 0%
Product Verification | 3/18 | 30 | 3/25 | 11.00 | 0.00 | 11.00 | 0%

Table 4: Project Schedule


Duration

Figure 5: Gantt Chart

### 1.3 Appendix 3 – Other Appendices

Other typical attachments that are added to bolster the competitiveness of your proposal:

- Technical references (in proper bibliographic form) including key URLs.
- Your drawings and schematics (rather than embedding in text)

Hand-drawn Schematic of the wireless circuit for edge sensors


Figure 6: Hand-drawn schematic


Figure 7: Butterfly diagram representing Current flow from battery to edge sensor

Power Budget:

Table 5: Power Budget

Observations:

1. Total Daily Energy Consumption: Adding up all the components, the system's total daily energy consumption is approximately 485.86 Wh/day.
2. Power-Hungry Components: The Raspberry Pi 5 and Raspberry Pi4 are the most power-intensive components. Optimizing their usage (e.g., powering down when idle) could significantly reduce energy consumption.
3. Low-Power Components: The BME688 sensor and motion sensor (HC-SR501) consume negligible power compared to other components, making them ideal for continuous monitoring.
4. Optimization Strategies:
- Used power-saving modes for ESP32 boards and sensors during idle periods.
- Limited camera and Coral USB Accelerator activity to motion-triggered events.
- Explored scheduling tasks on the Raspberry Pi to reduce active power usage.
Component | Voltage (V) | Current (mA) | Power (W) | Operating Time (hrs/day) | Energy Consumption (Wh/day)
Raspberry Pi 5 | 5.0 | 3000 | 15.0 | 24 | 360
ESP32 Boards (x3) | 3.3 | 200 each | 0.66 each | 24 | 47.52
HC-SR501 Motion Sensor | 5.0 | 50 | 0.25 | 24 | 6.0
Raspberry Pi HQ Camera | 5.0 | 250 | 1.25 | 8 (if motion detected) | 10.0
BME688 Sensor | 3.3 | 15 | 0.0495 | 24 | 1.188
TP-Link Kasa Smart Plug | 110-240 (AC) | 10 (standby) | 1.1 (standby) | 24 | 26.4
Coral USB Accelerator | 5.0 | 500 | 2.5 | 12 | 30.0
LED Indicators (x3) | 3.3 | 20 each | 0.066 each | 24 | 4.75
Mobile App (React Native) | N/A | N/A | N/A | N/A | N/A (powered by user devices)

Team Information Sheet

Akhil Bongu is a Computer Engineering major, with experience in training and deploying AI and Deep Learning models as an intern for NTT Data Business Solutions. He has worked with frameworks such as Pytorch and Tensorflow for a variety of use cases, from basic classification to computer vision.

Phone No: +1 (704)-605-7441
Email: akbongu@bu.edu

Anirudh Singh is a Computer Engineering major interested in pursuing AI and various other data driven solutions. Past experiences include Software Engineering intern at Cadence Design System under the Custom IC and Packaging group, with work spanning from API development to training and creating data pipelines for various machine learning models.

Phone No: +1 (857)-272-1560
Email: ansingh@bu.edu

Vansh Bhatia is a Electrical Engineer major with a minor in Manufacturing Engineering, passionate about advanced technological developments in the field of sustainable energy systems and power electronics. His experience in the Steel Industry at Frontier Alloy Steel Ltd, has made him well equipped in addressing real world manufacturing challenges.

Phone No: +1 (857)-318-7454
Email: vansh@bu.edu

Sreeram Andra is a dual degree candidate in Computer Engineering and Economics. He is passionate about Finance, Technology and the intersection of the two. His experience ranges in various fields of Fintech and Machine Learning; he is particularly passionate about the applications of Quantitative methods and Machine Learning in real-time market analysis.

Phone No.: +1 (440)-836-4899
Email: vssa8989@bu.edu

Team Story:

The Domus team was formed out of a shared vision among its members to redefine smart home technology by prioritizing privacy, efficiency, and user-centric design. Comprising engineers from diverse disciplines, the team recognized the growing need for home automation systems that deliver real-time control and enhanced security without compromising data privacy. Inspired by the Latin word "domus," meaning "home," the team set out to create an innovative, edge-computing-based solution that integrates seamlessly into modern lifestyles. Together, they aim to make Domus not just a product, but a step forward in creating smarter, safer, and more connected living spaces.

References

- Datasheets and Documentation:
Raspberry Pi 5: “Raspberry Pi 5 Specifications and User Manual.” Raspberry Pi Foundation, 2024.https://www.raspberrypi.com/documentation
ESP32: “ESP32 Technical Reference Manual.” Espressif Systems, 2024.https://www.espressif.com/en/support/download/documents
Coral USB Accelerator: “Coral USB Accelerator Datasheet.” Google Coral, 2024.https://coral.ai/products/accelerator
- AI and ML Frameworks:
OpenCV: “OpenCV Python Documentation.” OpenCV Team, 2024. https://docs.opencv.org
TensorFlow Lite for Coral: “TensorFlow Lite Model Optimization.” TensorFlow Team, 2024.https://www.tensorflow.org/lite
- Coral USB Accelerator:
“Coral USB Accelerator.” Google Coral, 2024. Available at: https://coral.ai/products/accelerator
- Environmental Sensors:
BME688: “BME688 Integrated Environmental Sensor Datasheet.” Bosch Sensortec, 2024.https://www.bosch-sensortec.com
- Energy Monitoring:
TP-Link Kasa Smart Plug: “KP115 User Manual.” TP-Link, 2024. https://www.tp-link.com
- Technical Reference for Coral USB Accelerator Setup:
“Setup Coral TPU USB Accelerator on Raspberry Pi 5.” DIY Engineers, May 18, 2024. Available at:
https://www.diyengineers.com/2024/05/18/setup-coral-tpu-usb-accelerator-on-raspberry-pi-5/#google_vignette (https://www.diyengineers.com/2024/05/18/setup-coral-tpu-usb-accelerator-on-raspberry-pi-5/)
- React Native Framework:
“React Native Documentation.” Meta, 2024. https://reactnative.dev

Authored by Venkata Sai Andra

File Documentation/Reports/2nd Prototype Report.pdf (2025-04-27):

# Second Prototype Test Report


Team 27
Domus: Smart Home Control

Venkata Sai Sreeram Andra vssa8989@bu.edu Anirudh Singh ansingh@bu.edu Vansh Bhatia vansh@bu.edu
Akhil Bongu akbongu@bu.edu

1

### Table of Contents

1 Required Materials | 3
1.1 Hardware: | 3
1.2 Software: | 3
2 Set Up | 4
2.1 Pre-testing Setup Procedure | 4
1. Power On the Raspberry Pi 5 and Raspberry Pi 4 | 4
2. Sensor Validation | 5
3. React Native App Setup | 5
4. Feature Verification | 5
2.2 Testing Procedure | 6
3 Measurable Criteria | 7
4 Conclusion | 8
4.1 Evaluation | 8
4.2 Problems | 8
4.3 Next Steps | 9
5 Appendix | 10

2

### 1 Required Materials

### 1.1 Hardware:

- Raspberry Pi 5 (with 32GB Amazon Basics microSDXC Class 10 memory card)
- 2 ESP32 Devkit S1 Micontrollers
- Raspberry Pi 4B
- BME688 Sensor
- Raspberry Pi AI Camera IMX 500
- HC-SR501 Motion sensor
- TP Link KP115 Smart Plug
- Verizon Wifi Router

### 1.2 Software:

- Python scripts:
- Collecting real-time sensor data (hosted using a Flask Server - using

websocket for real time alerting)

- Kasa API to link smart plug data to our personal app
- Streamed live video footage using Gstreamer Pipeline
- Face Recognition using dlib + OpenCV
- Object Detection using MobileNet SSD V2
- Activity Recognition using MoveNet + LSTM
- React Native:
- Integrated sensor data, face recognition functionality through iOS mobile

application.

3

### 2 Set Up

The Raspberry Pi 5 serves as the central microprocessor, coordinating data collection and

processing for the smart home system. All sensors are connected to ESP32 edge microprocessors

powered directly through the wall outlets to ensure circuit safety. The ESP32 devices wirelessly

transmit sensor data to the Raspberry Pi 5, where Python scripts process the information. The

Raspberry Pi AI camera is connected to a Raspberry Pi 4 through the MIPI CSI camera port,

which serves as its dedicated edge processor, and streams live footage wirelessly with the central

Raspberry Pi 5. The data collected from all sensors is displayed in real-time on a React Native

application, which provides interfaces for theft detection, motion sensing, environmental metrics

and energy tracking. The theft detection system utilizes a face recognition model built with

OpenCV and the face_recognition library from the dlib library.

### 2.1 Pre-testing Setup Procedure

1. Power On the Raspberry Pi 5 and Raspberry Pi 4
a. Connect the Raspberry Pi 5 to a power source using its USB-C cable. Ensure the

preloaded microSDXC card is already inserted.

b. Connect the Raspberry Pi 4 to a power source using its USB-C cable.
c. Wait for the Raspberry Pi 5 to boot up and verify its connection to the local Wi-Fi

network.

4

2. Sensor Validation
a. Ensure that the BME688 (air quality sensor) and HCS5-501 (motion sensor) are

getting powered from the wall outlets and wirelessly connected to the Raspberry Pi

5 via their respective ESP32 edge processors.

b. Run the pre-installed Python scripts on the Raspberry Pi 5 to confirm that the

sensor data is being transmitted and received correctly. Check the console logs for

errors or missing data.

c. If using the Kasa smart plug, make sure the appliance powered by it is well

connected and the plug’s blue light turns on.

3. React Native App Setup
a. Launch the React Native app on the connected mobile device or emulator. Ensure

the app loads to the home screen.

4. Feature Verification
a. Navigate to each screen in the app to verify that:
i. Motion Sensing: The app reflects motion detected by the HC-SR501

sensor.

ii. | Theft Detection: Specific screen within the mobile application displays
| real time alerts of unknown/authorized personnel appearing in the camera’s
| field of view.
iii. | Energy Tracking: The screen is set up to display current power/total
| energy consumption metrics in the form of time graphs once data
| integration is complete.

5


Figure 1: Illustration of Setup and Process Flow

2.2 Testing Procedure

1. Live Motion Detection: Wave hand in front of sensor (from up to 7 metres away)
2. Face Recognition: Should generate alerts for unknown/authorized personnel present in

the camera’s field of view in real time.

### 3. BME688 Sensor:

- Temperature/Humidity Measurement: Should display temperature (in ℃) and

humidity (in %)

- Air Quality: Gas resistance (in Ohms) & Air Quality indicator meter
- Atmospheric pressure (in hPa)

6

4. Energy tracking: Should generate real time power/energy consumption graphs for any

load connected to the smart plug.

### 3 Measurable Criteria

1. Motion Sensor: Detected any movement in front of the broad range of the sensor and

updated the status of the sensor on the app simultaneously.

2. Theft Detection Camera: The face detection system successfully distinguished between

authorized and unauthorized person and a real-time update for the same was on the app.

3. Temperature and other indoor environment data:
- Displayed temperature in Celsius and and humidity in percentage
- AQI meter with six different zones for indicating the air quality in a given room or

area

- Displayed atmospheric pressure in hPa
4. Energy Tracking: The energy screen on the app should show energy consumption and

overall power usage graphs and current values of a particular outlet and the connected

device and has ability to turn the connection “ON” or “OFF” through the mobile app.

7

### 4 Conclusion

### 4.1 Evaluation

The prototype’s functionality was as expected. The motion sensor and BME688 both relayed real

time values to the React-Native iOS application. The camera module was able to distinguish

between an authorized and unauthorized person, and was able to display an alert to the mobile

application in real-time with minimal latency. The smart plug also provided real time energy

consumption data to the mobile application, and allowed for remote on/off capabilities.

All the sensors connected to the Raspberry Pi 5 via the edge microcontrollers seamlessly as

expected. The response from the sensors was fast and without hitches, as shown in the figures

below.

### 4.2 Problems

- Network Connectivity Issues
- Challenge: Difficulty in maintaining stable communication through a single

network.

- Improvement: Implement a personal router with LAN connection to integrate

seamlessly with BU Wi-Fi.

- Ergonomic and Durable Housing
- Challenge: Designing compact and user-friendly housing units.
- Improvement: Optimize design using durable materials and modular components to

enhance usability and longevity.

8

- User Interface Design
- Challenge: Developing an intuitive and interactive UI.
- Improvement: Conduct further iterative development to improve user experience

and functionality.

- Camera Streaming Quality
- Challenge: Ensuring high-quality, low-latency streaming from the camera.
- Improvement: Experiment with alternative streaming protocols, stream directly to

the app, and execute inference on the camera itself to reduce latency.

### 4.3 Next Steps

- Optimize the in app LLM and integrate voice commands
- Improve the UI and make it more user friendly
- Train a more refined computer vision learning model for higher accuracy in object

detection and further use to efficient theft detection system

- Develop/3D-print a new plug-in housing unit for our edge sensors and a holder for the

camera

- Apply a linear regression model to do predictive analysis with energy consumption
- Figure out how to use the BU WiFi network on our local wifi router via LAN cable to

simultaneously use the LLM and camera footage on the application

9


### 5 Appendix

10


11

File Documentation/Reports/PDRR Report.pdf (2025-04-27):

## Boston University Electrical & Computer Engineering

EC463 Capstone Senior Design Project

## Problem Definition and Requirements Review

## Smart Home Control System

Submitted to
Alan Pisano

### 8 St. Mary’s Street Boston

Room 522
(617) 353-6264
apisano@bu.edu


Team 27
Domus
Venkata Sai Sreeram Andra vssa8989@bu.edu
Anirudh Singh ansingh@bu.edu Vansh Bhatia vansh@bu.edu
Akhil Bongu akbongu@bu.edu
Submitted: 17th October 2024

Client Sign-Off _____________________________________

### Smart Home Control System (Domus)

Table of Contents

Project Summary

The Smart Home Control and Security System with industrial IoT and LLM integration focuses on designing and implementing an innovative smart home system. The product ensures real-time security and privacy through edge-computing, also preventing potential data loss. Raspberry Pi allows us to have a basic platform to test the initial functionality of the sensors; however, this will be enhanced via mobile app development where we plan on using either Swift or Android Studio to create a personalized UI. The Raspberry Pi will act as the central unit, with Coral AI boards supporting the LLM-driven processing. Overall, this project provides a comprehensive management over everyday home devices in addition to smart features such as theft detection, energy consumption suggestions, and greater privacy via edge-computing.

1 Need for this Project

Modern homes suffer from the trouble of distributed automation systems such as one for security, one for energy management, etc. As many solutions currently in the market operate independently from one another, such as Google Nest for smart home devices and ADT service for security, leading to an efficient user experience. In addition, almost all products in the market rely heavily on cloud-based services, which tend to increase service disruptions and could cause data loss, making the home management cumbersome and complex for most users.
As the world is moving towards a more convenient route and focus on streamline processes is now more than ever, customers tend to demand seamless control without complex setup and expect real-time insights regarding energy consumption in order to make informed decisions. Privacy is also a major concern in today’s world and users are becoming more skeptical of sharing their data with systems on the market.
This project addresses these challenges by developing a unified smart home platform using Raspberry Pi and Coral AI boards, integrating automation, security, and energy management. It leverages edge computing for fast, reliable control without cloud reliance, enhancing efficiency and privacy. With industrial IoT integration, the system offers advanced automation and real-time monitoring of energy use and air quality, while also ensuring data integrity. This solution empowers users to manage their homes efficiently while promoting a more sustainable future.

2 Problem Statement and Deliverables

Problem Statement
This project solves the need for a smart home system offering real-time control and security with enhanced privacy by integrating edge-computing, offering a one-stop solution.

Deliverables:

Hardware:

- A Raspberry Pi-based central unit integrated with sensors (for security, environmental monitoring, and automation) and connectivity modules (Wi-Fi, Bluetooth, Zigbee).
- Actuators and devices (e.g., smart locks, lights) connected to the system to demonstrate home automation capabilities.

Software
- A control application with a user-friendly interface for managing devices, security alerts, and energy monitoring.
- A locally deployed LLM to process voice commands, ensuring privacy and seamless operation without cloud dependency.
- Automated routines for air quality, energy tracking, and real-time alerts for security events.

Data and Simulation
- SystemC simulation results demonstrate the system’s performance, including the interaction between hardware and software components.
- Predictive models for energy tracking and security scenarios tested through simulations to validate system behavior under different conditions.
- Logs and metrics for data-driven insights, showcasing the efficiency of edge computing and offline functionality.

3 Visualization


Figure 1: Hardware and Communication Flow

This figure illustrates the interactions between the user, application, and hardware components in the Smart Home Control and Security System. It demonstrates how the Raspberry Pi 5 serves as the central hub, integrating sensors (temperature, air quality, and motion), and controlling smart appliances and security features through an 8-channel relay. The Coral AI USB Accelerator enhances processing efficiency, supporting LLM-based automation. Communication flows through the internet and application interface, enabling real-time monitoring, energy tracking, and theft detection.


Figure 2: Use-Case UML Diagram

This diagram illustrates the interactions between the homeowner and the various components of the smart home system. Key features include surveillance, home automation, theft detection, energy tracking, and air quality monitoring, all managed through a unified platform. The Large Language Model (LLM) provides enhanced automation and control, integrating with modules such as motion sensing and device management. Edge computing ensures seamless, real-time processing with minimal cloud dependence, promoting privacy and efficiency.

4 Competing Technologies
This section highlights competing technologies addressing similar challenges to our Smart Home System, which integrates automation, security, energy tracking, and air quality monitoring with a focus on privacy. Key competitors influenced our design choices, as outlined below:

Google Nest

| ● Overview: Cloud-based smart home ecosystem with AI-driven automation. ● Key Features: ○ Cloud infrastructure for control and analytics ○ Smart energy management via thermostats and appliances ○ AI-based behavior learning and automation ○ Centralized control through Google Home app ● Design Insight: Inspired by Nest’s energy tracking, we incorporated predictive energy models. To address cloud-related privacy and latency concerns, we used edge computing for offline functionality.

Amazon Alexa

| ● Overview: Voice-controlled smart home platform with extensive device support. ● Key Features: ○ Voice-based control ○ Broad third-party interoperability ○ Routine automation via cloud services ○ Continuous learning for better voice recognition ● Design Insight: Alexa’s broad compatibility led us to support Wi-Fi, Bluetooth, and Zigbee. Inspired by seamless voice control, we integrated a local LLM to enhance privacy with cloud-independent operations.

Home Assistant

| ● Overview: Open-source platform offering flexible, local control with minimal cloud reliance. ● Key Features: ○ Community-driven customization ○ Support for multiple protocols (Wi-Fi, Zigbee, Bluetooth) ○ Local control for enhanced privacy ○ Integration with third-party services

- Design Insight: We adopted Home Assistant’s flexibility for broad protocol support while adding advanced security features like theft detection. Our edge-computing approach aligns with its local control for privacy and offline capability.

Apple HomeKit

- Overview: Privacy-focused ecosystem with secure communication and limited third-party integrations.
- Key Features:
- End-to-end encryption
- Centralized control via the Home app
- Controlled ecosystem with limited external device support
- Design Insight: Inspired by HomeKit’s focus on privacy, we implemented secure communication while supporting broader interoperability than Apple’s closed system.

Relevant Standards and Patents

- Key Features:
- IEEE IoT Standards: Ensure interoperability across Wi-Fi, Bluetooth, and Zigbee.
- ISO Smart Home Standards: Provide security and automation frameworks.
- Patents: Emphasize energy management and edge computing best practices.
- Design Insight: Compliance with these standards ensures compatibility and security, while patents inspired our predictive energy tracking models for efficiency.

This comparison guided our system’s development, ensuring it remains privacy-focused, flexible, and compliant with industry standards.

5 Engineering Requirements

Performance Objectives:
| ● Response time: < 200ms ● Security detection accuracy: > 95% ● LLM inference: < 500ms per command ● Compliance with Wi-Fi, Bluetooth and Zigbee devices

Constraints:
| ● The system must operate efficiently on a Raspberry Pi platform (core) parallel to Coral AI boards ● Local LLM model RAM usage must not exceed 500MB ● The system should handle up to 30 connected devices at maximum capacity ● Must comply with data privacy regulations, limiting external data transmission as the system is mainly based on edge computing

Functions:
| ● Automation: Real-time control of multiple parallel devices ● Surveillance: Real-time monitoring through cameras and motion sensors ● Energy Management: Analyze trends and suggest optimizations for energy use ● Air Quality Monitoring: Alert users when AQI exceeds safe thresholds

Means:
| ● Raspberry Pi 5B: Serves as the core between all home automation activities, theft detection and energy tracking ● Coral AI USB accelerator: Supports computational demands to run locally on raspberry pi for reduced response time ● Zigbee Devices: Used for collecting energy consumption data from home appliances ● Sensors and Camera: Real time data collection by object detection and motion recognition

6 Appendix

References:

| ● Data Privacy concerns. Retrieved from: https://www.robin-data.io/en/data-protection-academy/news/smart-home-applic ations-data-protection#:~:text=Automatic%20data%20collection%3A%20Many%2 0smart,collected%20by%20smart%20home%20devices. (https://www.robin-data.io/en/data-protection-academy/news/smart-home-applications-data-protection) ● Raspberry Pi Foundation. Raspberry Pi Documentation. Retrieved from: https://www.raspberrypi.com/documentation/ ● Google Nest. Google Nest Overview. Retrieved from https://www.cnet.com/home/smart-home/everything-you-want-to-know-about-go ogle-home/ (https://www.cnet.com/home/smart-home/everything-you-want-to-know-about-google-home/) ● Amazon. Alexa Features and Overview. Retrieved from https://www.aboutamazon.com/news/devices/alexa-emergency-assist ● Maring, J. Amazon Alexa: Everything You Need to Know About the Heart of the Echo. Retrieved from https://www.androidcentral.com ● Home Assistant. Home Assistant Documentation. Retrieved from https://www.home-assistant.io ● Apple. Apple HomeKit Overview and Support. Retrieved from https://support.apple.com/explore/homekit ● Raspberry Pi. Raspberry Pi 5 https://www.nextpcb.com/blog/raspberry-pi-5-as-a-home-automation-hub

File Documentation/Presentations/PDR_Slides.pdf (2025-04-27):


# PDR

# Team 27 - Domus

# Introduction

## Sreeram Andra

## Computer Engineer: vssa8989@bu.edu

## Anirudh Singh

## Computer Engineer: ansingh@bu.edu

## Vansh Bhatia

## Electrical Engineer: vansh@bu.edu

## Akhil Bongu

## Computer Engineer: akbongu@bu.edu

# Problem Statement

## This project solves the need for a smart home system offering real-time control and security with enhanced privacy by integrating

edge-computing, offering a one-stop solution.

# Deliverables (Fall 2024)

## - Motion Detection

## - Facial Recognition

## - Environmental Monitoring

## - Energy Monitoring

## - Mobile Application Features

## - LLM Integration

## - System Performance

# System Block Diagram


# Design Review/Technologies used

HARDWARE COMPONENT | PURPOSE
Raspberry Pi 5 | Central microprocessor
Raspberry Pi 4B | Microprocessor/Camera
ESP 32 | Microprocessor/Edge Sensors
Edge Sensors | Collect Data
Smart Plug | Measures Energy Consumption
Camera | Collects Video Footage
Edge Modules | Houses Edge Circuits
Coral AI USB Accelerator | Boosts Inference Capabilities

# Design Review/Technologies used

SOFTWARE COMPONENT | PURPOSE
Raspberry Pi OS | Calibration of Pi 5
C++ Code Files | Collect data from edge sensors
LLM (GPT 3.5 Turbo) | User interactivity
React-Native | UI Interface
Computer Vision Model (dlib + OpenCV) | Facial Recognition
SolidWorks | Housing Unit Design
SQLite | Database Storage
WebSocket protocol | Two way real time data communication
Gstreamer protocol | Live streaming of camera footage

# Test Results

FEATURE | METRIC | OUTCOME
Motion Detection | Detection Accuracy | 100%
Theft Detection | Facial recognition latency | <1 second
Environmental Sensing | Temperature Accuracy | ±1°C
| Humidity Accuracy | ±2%
Energy Tracking | Toggle latency for devices | <1 second
| Real-time power consumption display | Accurate

# Deliverables (Spring 2025)

## - Predictive Analysis of Energy Usage

## - Fully functional user friendly LLM

## - Activity Recognition and Alert System

## - Fully functional Theft Detection

## - Deployable Application with desired User-Experience

## - Final Housing Unit(s)

# Schedule


# THANK YOU!

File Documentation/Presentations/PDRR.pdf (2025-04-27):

## Project Title

Team Number_________________

Customer_____________________

# Smart Home Control System

# Venkata Sai Andra, Anirudh Singh, Akhil Bongu, Vansh Bhatia

## Smart Home System

Student-defined

## Project Title

Customer_____________________

# Problem Statement

Self-defined

# This project solves the need for a smart home system offering real-time control and security with enhanced privacy by

integrating edge-computing, offering a one-stop solution.

## Smart Home System

## Project Title

Customer_____________________

# Deliverables

Self-defined

## Hardware

- A Raspberry Pi-based unit integrated with sensors and connectivity modules.

### Software

- An application for controlling the devices and monitoring the security features,

### that also uses a locally deployed LLM for processing user commands

### Data and Simulation - SystemC simulation results that will demonstrate the performance of the hardware-software integration

## Smart Home System

## Project Title

Customer_____________________

# Requirements

Self-defined

Functions
- Home automation: Real-time control of home devices based on predefined rules.
- Surveillance: Secure management using live camera monitoring, real-time theft detection system
- Energy Tracking: Models energy consumption trends based on historical usage and makes predictions/suggestions.
- Air Quality Detection: Relays real-time AQI to the application and warns user if AQI > 100.

Objectives
- Ensure local processing with a response time of less than 200ms.
- > 95% accuracy in detecting movement and security breaches.
- < 500ms per command processed for LLM model inference.
- Maintain data privacy through edge computing
- Ensure compatibility with existing home automation standards like Wi-Fi, Bluetooth, and Zigbee.

## Smart Home System

Project Title; Customer_____________________; Requirements; Self-defined; Constraints; Coral AI boards.; transmission.; Smart Home System

- The system must operate on a Raspberry Pi with additional processing power provided by
- Local LLM should consume less than 500MB RAM to run efficiently on edge devices.
- The system should handle up to 30 connected devices simultaneously.
- Must comply with local data privacy regulations, restricting external data storage and

## Project Title

# Visualization


Customer_____________________

Self-defined

## Smart Home System

RASPBERRY PI 5

Project Title; Customer_____________________; Self-defined; Smart Home System Smm

## Popular competing Technologies/Other Products

Google Nest

Used for: Smart home automation hub with security features.

Amazon Alexa & Ring

Used for: Voice-controlled automation with theft detection.

Apple HomeKit

Used for: Privacy-focused home automation system.

Project Title; Customer_____________________; Self-defined; Smart Home System Smm

## Comments/Questions?

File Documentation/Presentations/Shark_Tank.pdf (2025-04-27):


Anirudh Singh, Venkata Sai Sreeram Andhra, Vansh Bhatia, Akhil Bongu

## Value Proposition

- Domus is an integrated automation and security solution
- Targeted towards homeowners and businesses seeking reliable automation and security
- Real-time control and security with privacy and minimal cloud reliance
- Provides privacy-enhanced, real-time control over home devices and security systems with seamless edge computing
- Unlike Google Nest or Amazon Alexa, which rely heavily on cloud-based processing
- Our product performs all operations locally, ensuring fast response times, enhanced data privacy, and greater user control.

## Domus: Smart Home Control and Security System

- Description: A modern smart home solution that integrates IoT devices and AI for secure and efficient automation
- Societal Impact: Enhances privacy, security, and energy efficiency while reducing dependence on cloud processing
- Key Differentiators:
- Privacy-First Design: Local processing with an edge-deployed LLM ensures user privacy
- Fast and Responsive: Real-time control and command processing with less than 200ms response time
- Local Theft Detection and LLM: Integrates on-device face recognition for real-time theft detection and a local language model (LLM) for natural, private user interactions

## Technology Solution

- Raspberry Pi with Coral AI:
- Serves as a core link between environment and user and decreases response time by locally handling LLM
- Integrated IoT Components:
- Long range Wifi, Bluetooth IoT devices for diverse connectivity and Zigbee smart home devices for initial testing
- SystemC Simulation and SysML Documentation:
- Ensures reliable hardware-software integration and scalability.
- Local LLM:
- Processing requests and responses
- Facial Recognition:
- Using opencv and haarcascade to recognize faces and prevent theft


## MVP

- Local Control & Automation: Manage devices using Raspberry Pi with edge computing
- IoT Integration: Support for Zigbee-enabled smart devices.
- Fast Response: Actions completed under 200ms without cloud reliance
- Local LLM UI: On-device language model for natural user interaction
- Face Recognition Security: Detect unauthorized access via face recognition
- Easy Setup & Scalable: Minimal setup with architecture designed for future expansion

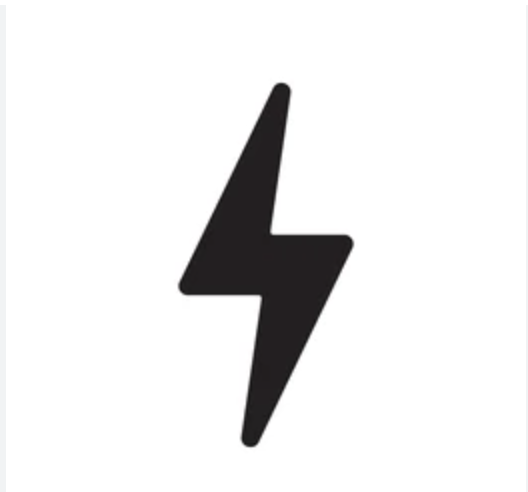
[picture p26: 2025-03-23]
Software/Frontend/Domus_Application/assets/flash.png

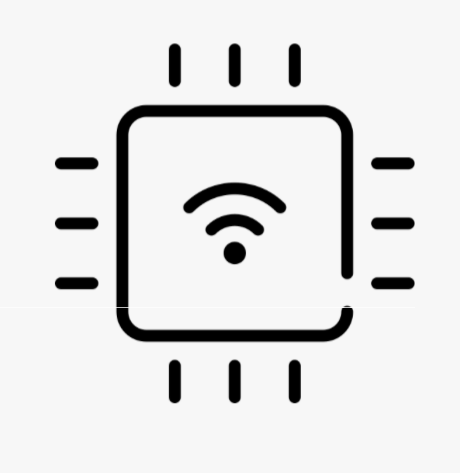
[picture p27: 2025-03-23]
Software/Frontend/Domus_Application/assets/device.png

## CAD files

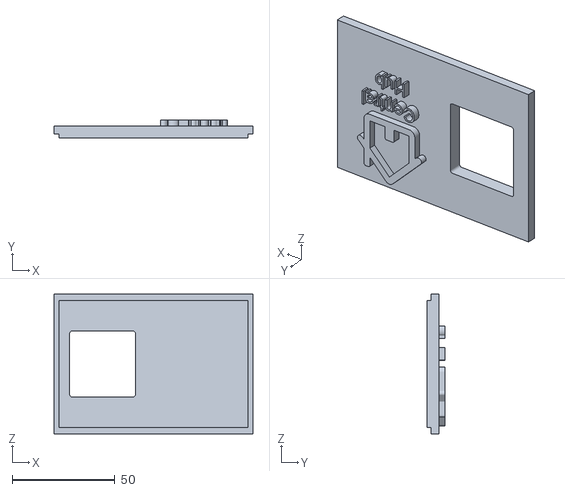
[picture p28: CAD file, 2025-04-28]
Hardware/CAD Models/Edge Sensor Housings/Housing CAD Files/mainhousing_lid.STL
97.0 x 9.00 x 68.0

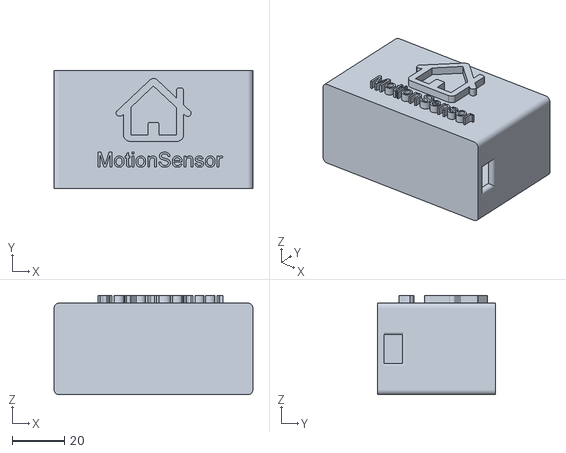
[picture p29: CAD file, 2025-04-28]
Hardware/CAD Models/Edge Sensor Housings/Housing CAD Files/motion sensor base.STL
76.0 x 45.0 x 38.0

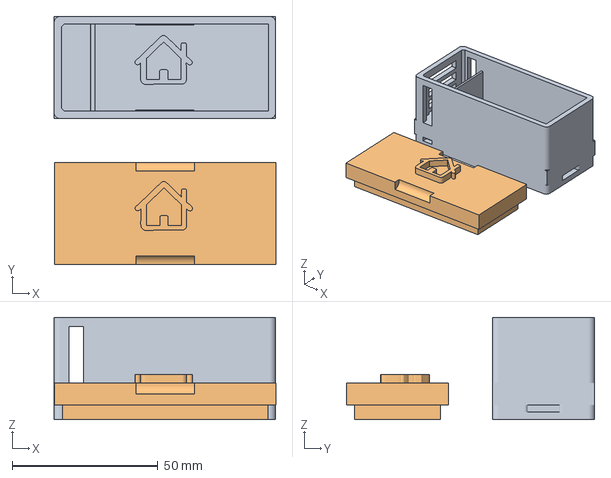
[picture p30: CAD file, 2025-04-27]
Hardware/CAD Models/Edge Sensor Housings/Housing gcode files/BME688 Housing.3mf
76.1 x 85.1 x 35.0 mm
BME688 BASE
BME688 LID (1).STL

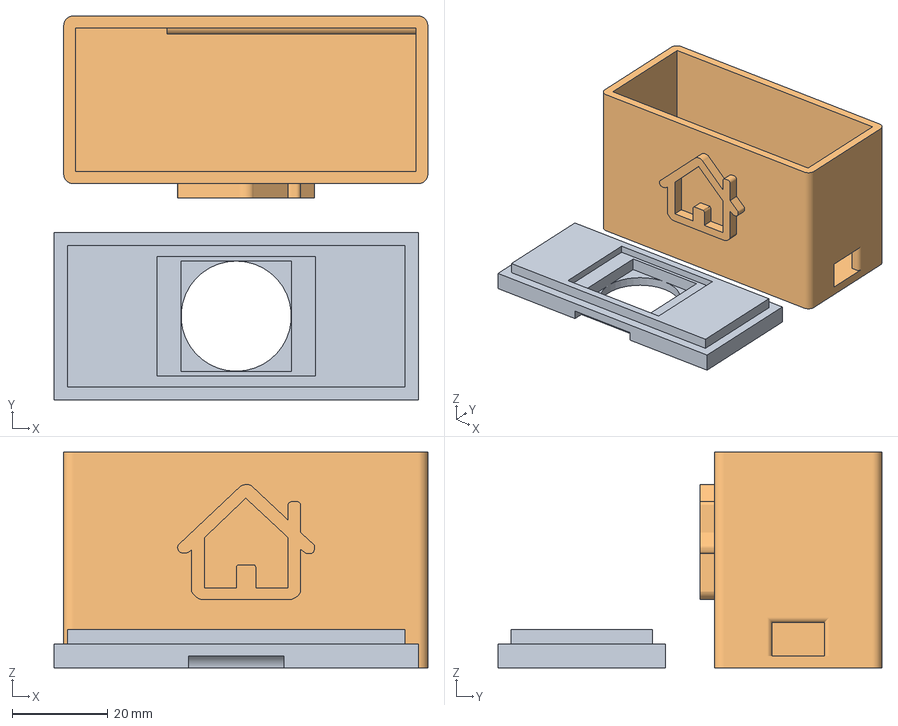
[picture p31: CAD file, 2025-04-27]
Hardware/CAD Models/Edge Sensor Housings/Housing gcode files/motion sensor Housing.3mf
78.0 x 80.1 x 45.0 mm
MOTION SENSOR LID (1).STL
motion sensor base.STL

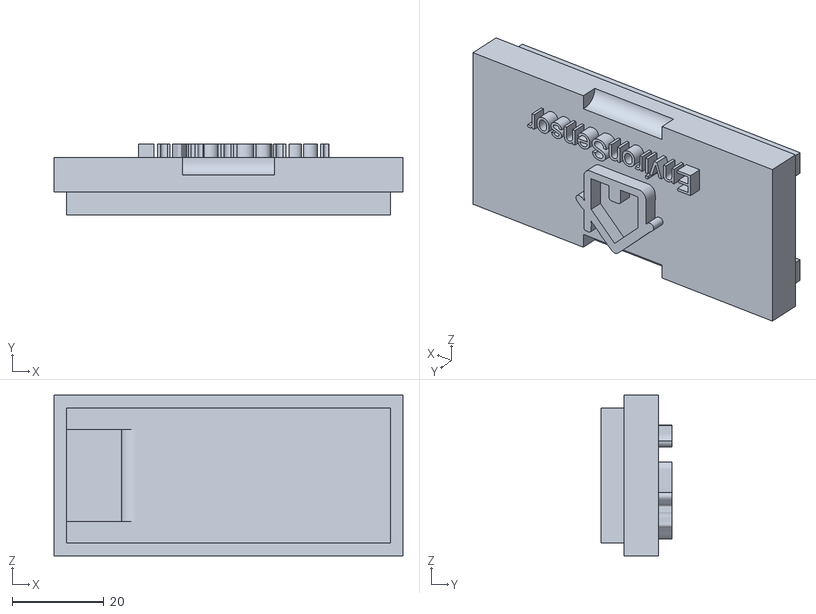
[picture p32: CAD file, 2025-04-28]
Hardware/CAD Models/Edge Sensor Housings/Housing CAD Files/BME688 LID.STL
76.0 x 15.5 x 35.0

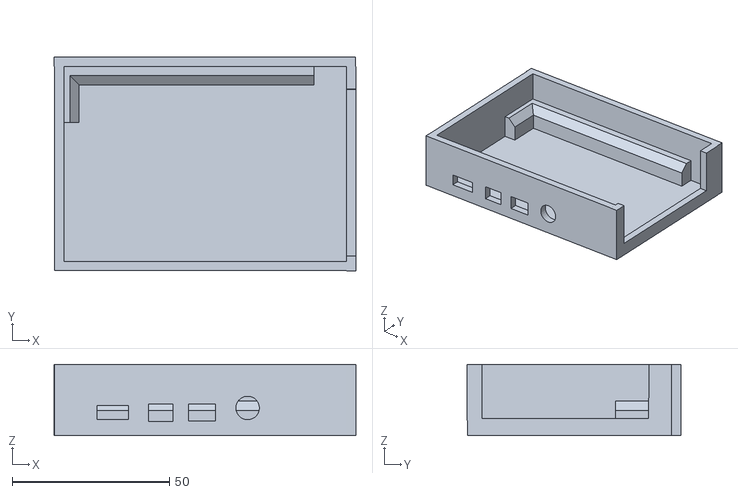
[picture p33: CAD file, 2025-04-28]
Hardware/CAD Models/Edge Sensor Housings/Housing CAD Files/pi5_base.stl
96.1 x 68.1 x 22.7

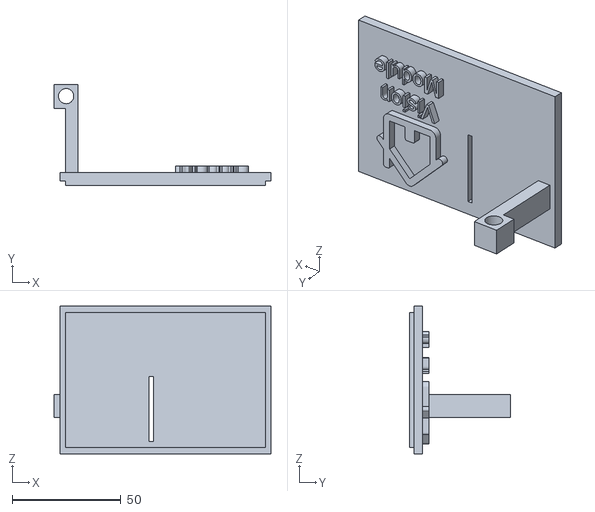
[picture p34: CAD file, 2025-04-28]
Hardware/CAD Models/Edge Sensor Housings/Housing CAD Files/camera_lid.STL
99.7 x 46.4 x 68.0

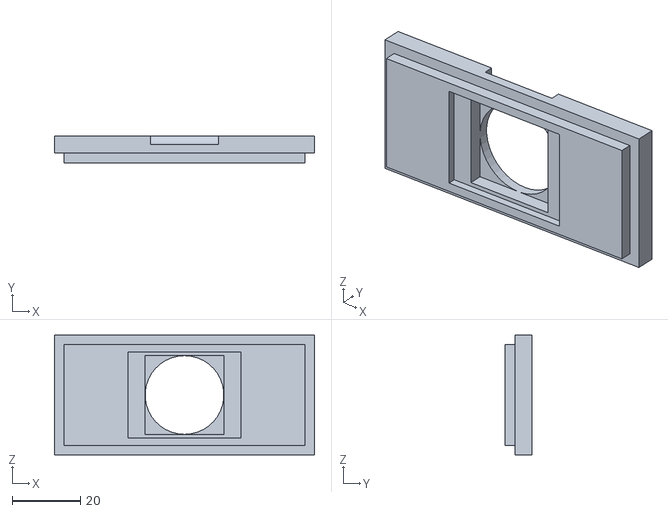
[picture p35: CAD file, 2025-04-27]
Hardware/CAD Models/Edge Sensor Housings/Housing CAD Files/MOTION SENSOR LID (1).STL
76.0 x 8.00 x 35.0

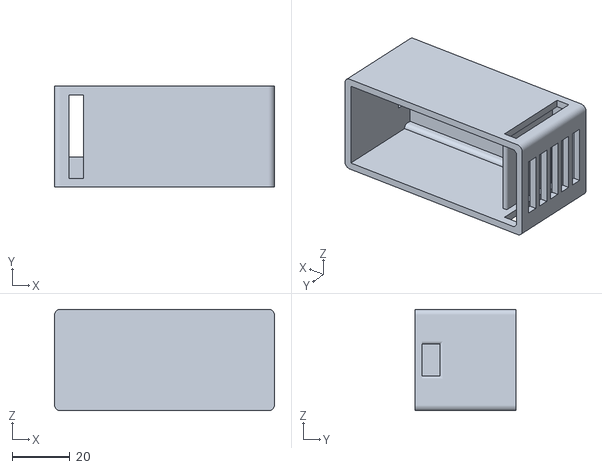
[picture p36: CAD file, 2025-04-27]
Hardware/CAD Models/Edge Sensor Housings/Housing CAD Files/BME688 BASE.STL
76.0 x 35.0 x 35.0

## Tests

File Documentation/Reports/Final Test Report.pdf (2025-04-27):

# Final Prototype Test Report

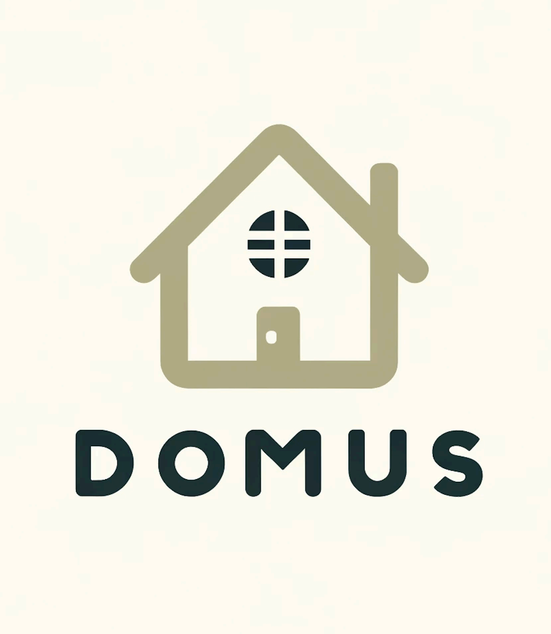
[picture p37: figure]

Team 27
Domus: Smart Home Control

Venkata Sai Sreeram Andra vssa8989@bu.edu Anirudh Singh ansingh@bu.edu Vansh Bhatia vansh@bu.edu
Akhil Bongu akbongu@bu.edu

1

### Table of Contents

1 Required Materials | 3
1.1 Hardware: | 3
1.2 Software: | 3
2 Set Up | 4
2.1 Pre-testing Setup Procedure | 4
1. Power On the Raspberry Pi 5 and Raspberry Pi 4 | 4
2. Sensor Validation | 5
3. React Native App Setup | 5
4. Feature Verification | 5
2.2 Testing Procedure | 6
3 Measurable Criteria | 7
4 Conclusion | 8
4.1 Evaluation | 8
4.2 Problems | 8
4.3 Next Steps | 9
5 Appendix | 10

2

### 1 Required Materials

### 1.1 Hardware:

- Raspberry Pi 5 (with 32GB Amazon Basics microSDXC Class 10 memory card)
- 2 ESP32 Devkit S1 Micontrollers
- Raspberry Pi 4B
- BME688 Sensor
- Raspberry Pi AI Camera IMX 500
- HC-SR501 Motion sensor
- TP Link KP115 Smart Plug
- Verizon Wifi Router
- Housing Units

### 1.2 Software:

- Python scripts:
- Collecting real-time sensor data (hosted using a Flask Server - using

WebSocket for real-time alerting)

- Kasa API to link smart plug data to our app
- Streamed live video footage using Gstreamer Pipeline
- Face Recognition using dlib + OpenCV
- Object Detection using MobileNet SSD V2
- Activity Recognition using MoveNet + LSTM
- React Native:

3

- Integrated sensor data and face recognition functionality through iOS

mobile application.

### 2 Set Up

The Raspberry Pi 5 serves as the central processor, managing data collection and processing for

the smart home system. ESP32 microcontrollers, powered via wall outlets for safety, collect

sensor data and transmit it wirelessly to the Pi 5, where Python scripts handle processing. A

Raspberry Pi 4, connected to the Raspberry Pi AI camera via MIPI CSI, acts as a dedicated edge

device, streaming video wirelessly to the central Pi. An iOS app displays real-time sensor data,

supporting features like theft detection, motion sensing, environmental monitoring, and energy

tracking. Theft detection is powered by a face recognition model using OpenCV and

face_recognition from the dlib library.

### 2.1 Pre-testing Setup Procedure

1. Power On the required devices
a. Connect the Raspberry Pi 5 to a power source using its USB-C cable. Ensure the

preloaded microSDXC card is already inserted.

b. Connect the Raspberry Pi 4 to a power source using its USB-C cable.
c. Connect the Kasa Smart Plug to any appliance of your choice
d. Connect the edge sensors to wall sockets (could be any desirable space in the house

as per the user)

4

2. Open the Domus Application
a. Log in to the application using your Gmail account
b. Go to the “Devices” screen on the application and follow the instructions to add the

motion sensor and temperature sensor.

c. Go back to the home page and make sure relevant real-time data is displayed.
3. Feature Verification
a. Navigate to each screen in the app to verify that:
i. Home Screen: This screen displays the relevant data in terms of connected

sensors.

ii. | Energy Screen: The screen is set up to display current power/total energy
| consumption metrics in the form of time graphs.
iii. | Devices Screen: The screen allows you to add new sensors by sending your
| WiFi credentials to the new, local ESP32.
iv. | Surveillance Screen: This screen within the mobile application displays
| real-time alerts of unknown/authorized personnel appearing in the camera’s
| frame.

5

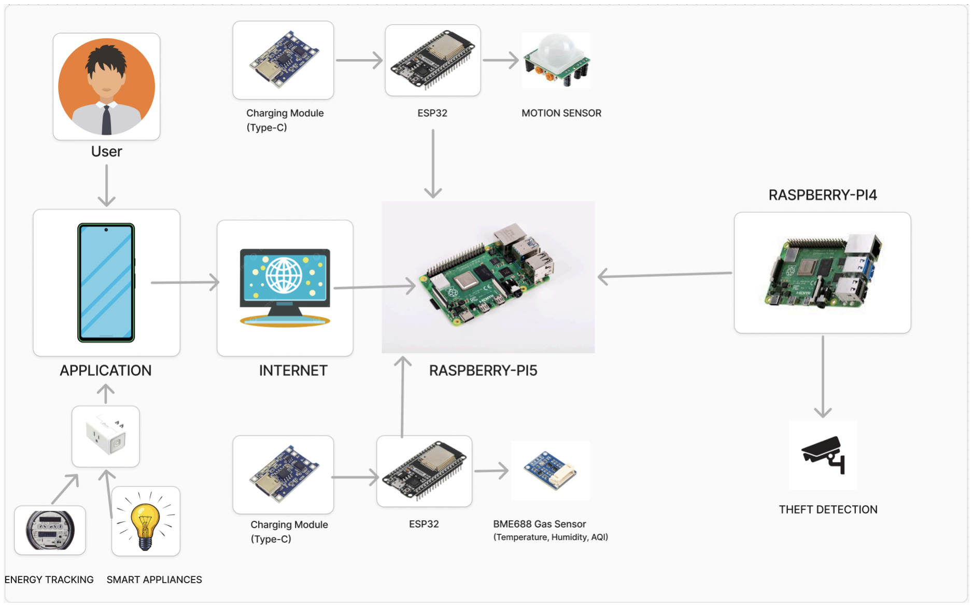
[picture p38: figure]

Figure 1: Illustration of Setup and Process Flow

2.2 Testing Procedure

1. Live Motion Detection: Wave hand in front of sensor (from up to 7 metres away)
2. Face Recognition: Should generate alerts for unknown/authorized personnel present in

the camera’s field of view in real time.

3. Object Detection: Display various objects in the camera's frame, which are then labeled

with percentage scores to depict the accuracy in the surveillance screen.

### 4. BME688 Sensor:

- Temperature/Humidity Measurement: Should display temperature (in ℃) and

humidity (in %)

6

- Air Quality: Gas resistance (in Ohms) & Air Quality indicator meter
- Atmospheric pressure (in hPa)
5. Energy tracking: Should generate real time power/energy consumption graphs for any

load connected to the smart plug.

6. Adding a Device: Should be able to add a new device

### 7. Pairing a Device: Should be able to view existing connections with an option to pair

within the client’s environment.

### 3 Measurable Criteria

1. Motion Sensor: Detected any movement in front of the broad range of the sensor and

updated the status of the sensor on the app simultaneously.

2. Surveillance: The face detection system successfully distinguished between authorized

and unauthorized person and a real-time update for the same was on the app.

3. Temperature and other indoor environment data:
- Displayed temperature in Celsius and and humidity in percentage
- AQI meter with six different zones for indicating the air quality in a given room or

area

- Displayed atmospheric pressure in hPa
4. Energy Tracking: The energy screen on the app should show energy consumption and

overall power usage graphs and current values of a particular outlet and the connected

device and has ability to turn the connection “ON” or “OFF” through the mobile app.

7

5. Device Pairing: Enables users to discover and pair ESP32-based sensors connected to the

same network using periodic backend check-ins. Available devices are displayed with

relevant icons, and users can pair them with a single tap, after which the app persistently

tracks their status for seamless integration.

### 4 Conclusion

### 4.1 Evaluation

The final prototype’s functionality was as expected. The motion sensor and BME688 both relayed

real-time values to the React-Native iOS application. The camera module was able to distinguish

between an authorized and unauthorized person and was able to display an alert to the mobile

application in real-time. The smart plug also provided real-time energy consumption data to the

mobile application and allowed for remote on/off capabilities.

All the sensors connected to the Raspberry Pi 5 via the edge microcontrollers seamlessly as

expected. The response from the sensors was fast and without hitches, as shown in the figures

below.

### 4.3 Scope of upgrades for ECE day

- Implement a “Wake Word” within the LLM functionality for an efficient interaction
- Train a more refined computer vision learning model for higher accuracy in object

detection.

8

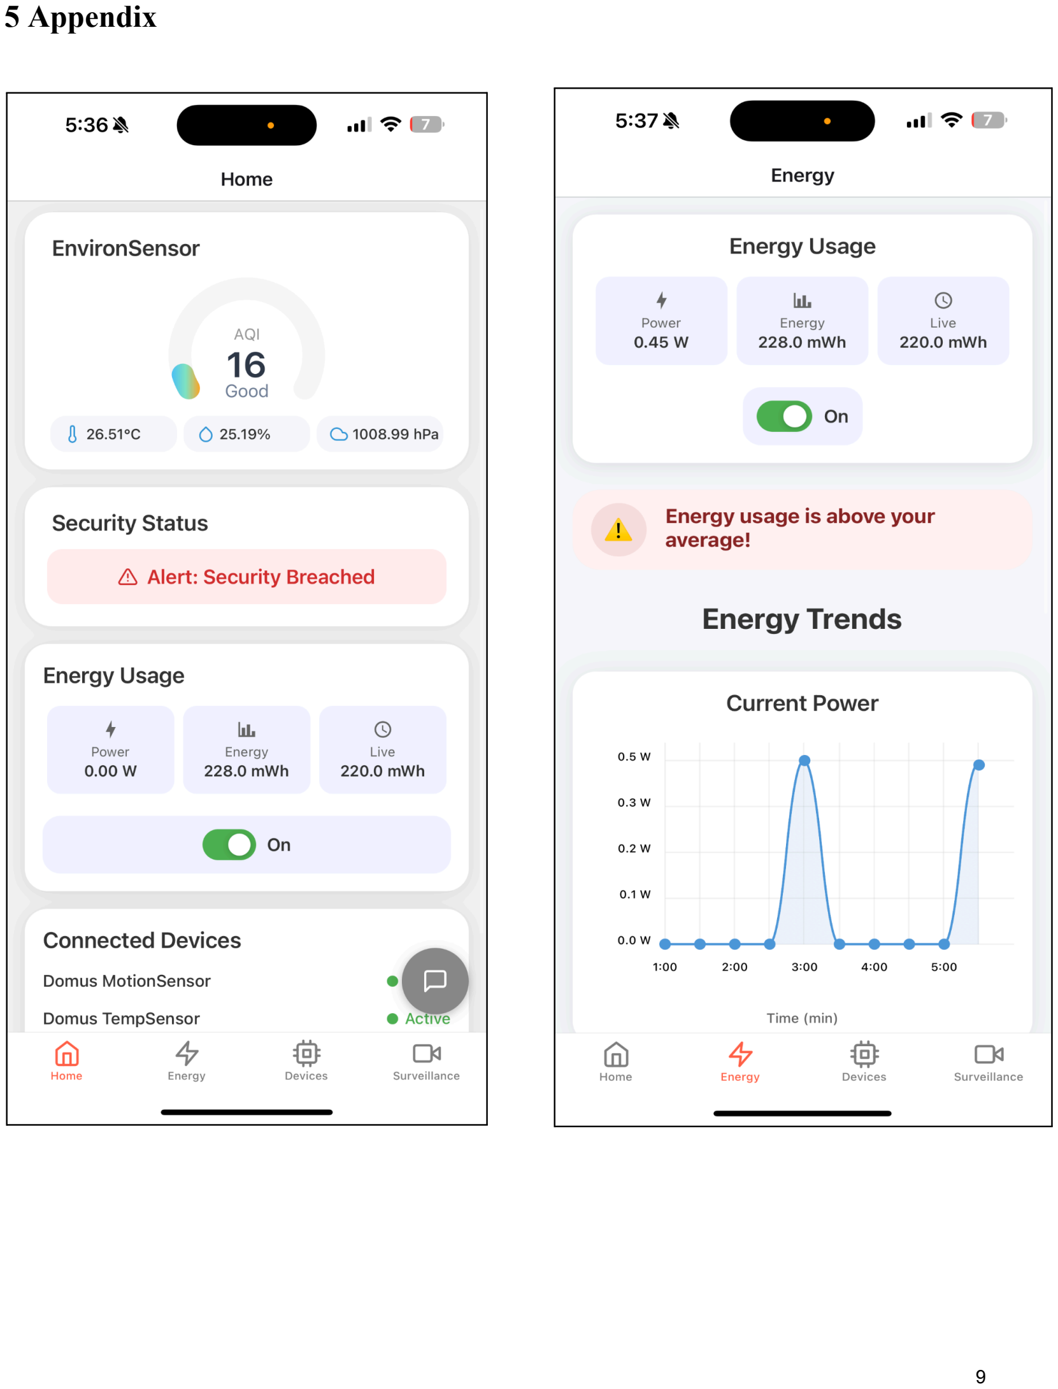
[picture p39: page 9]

### 5 Appendix

9

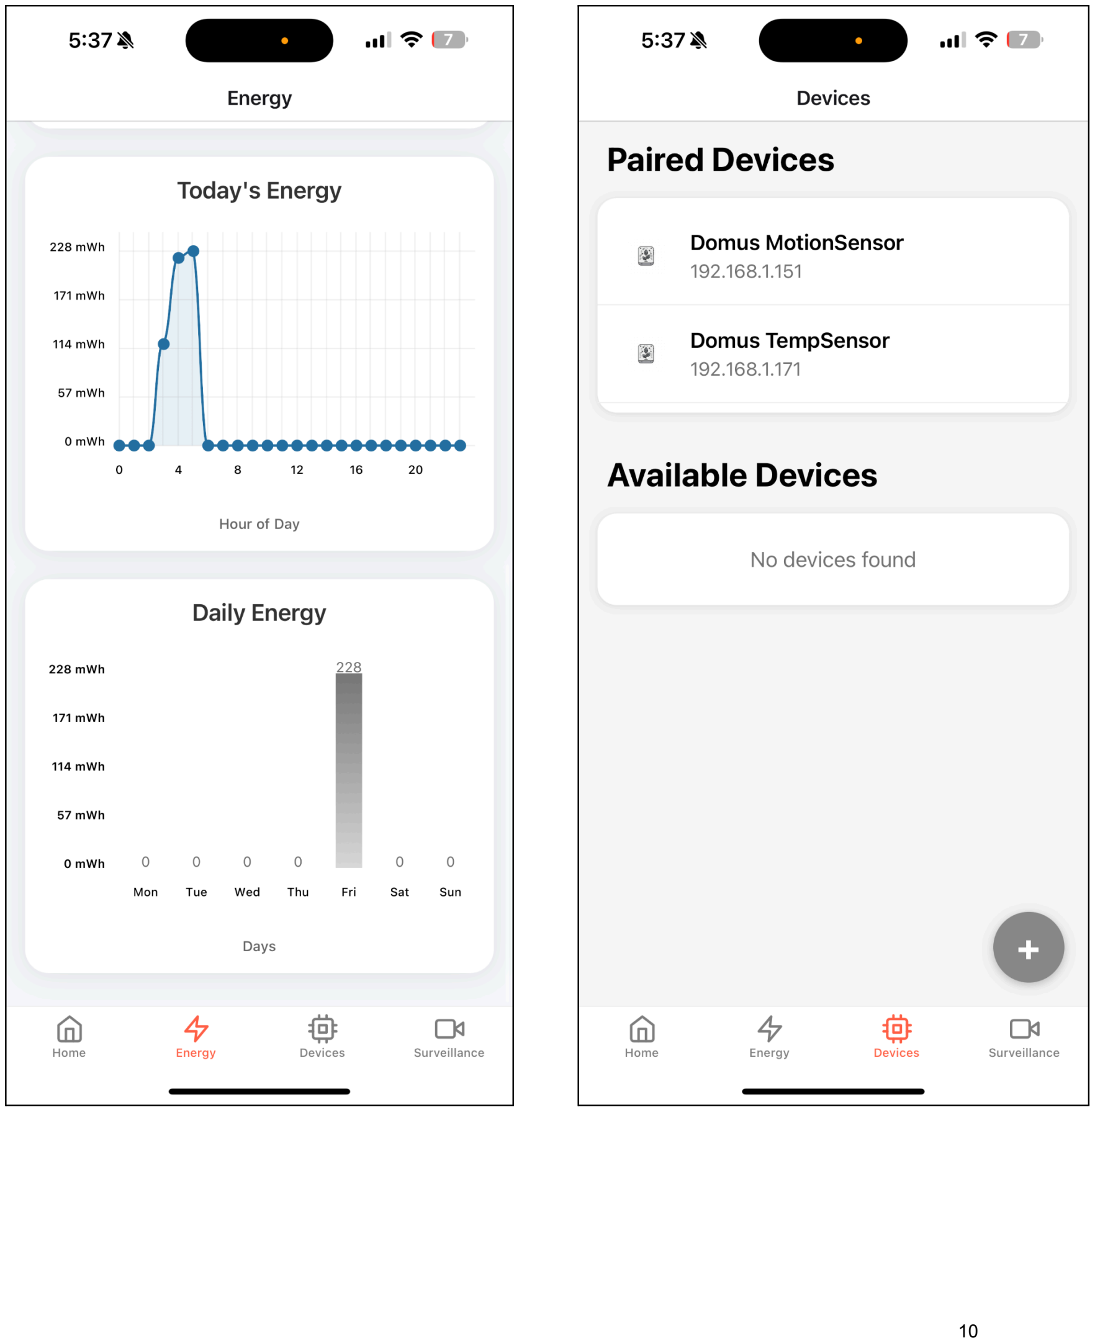
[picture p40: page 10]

10

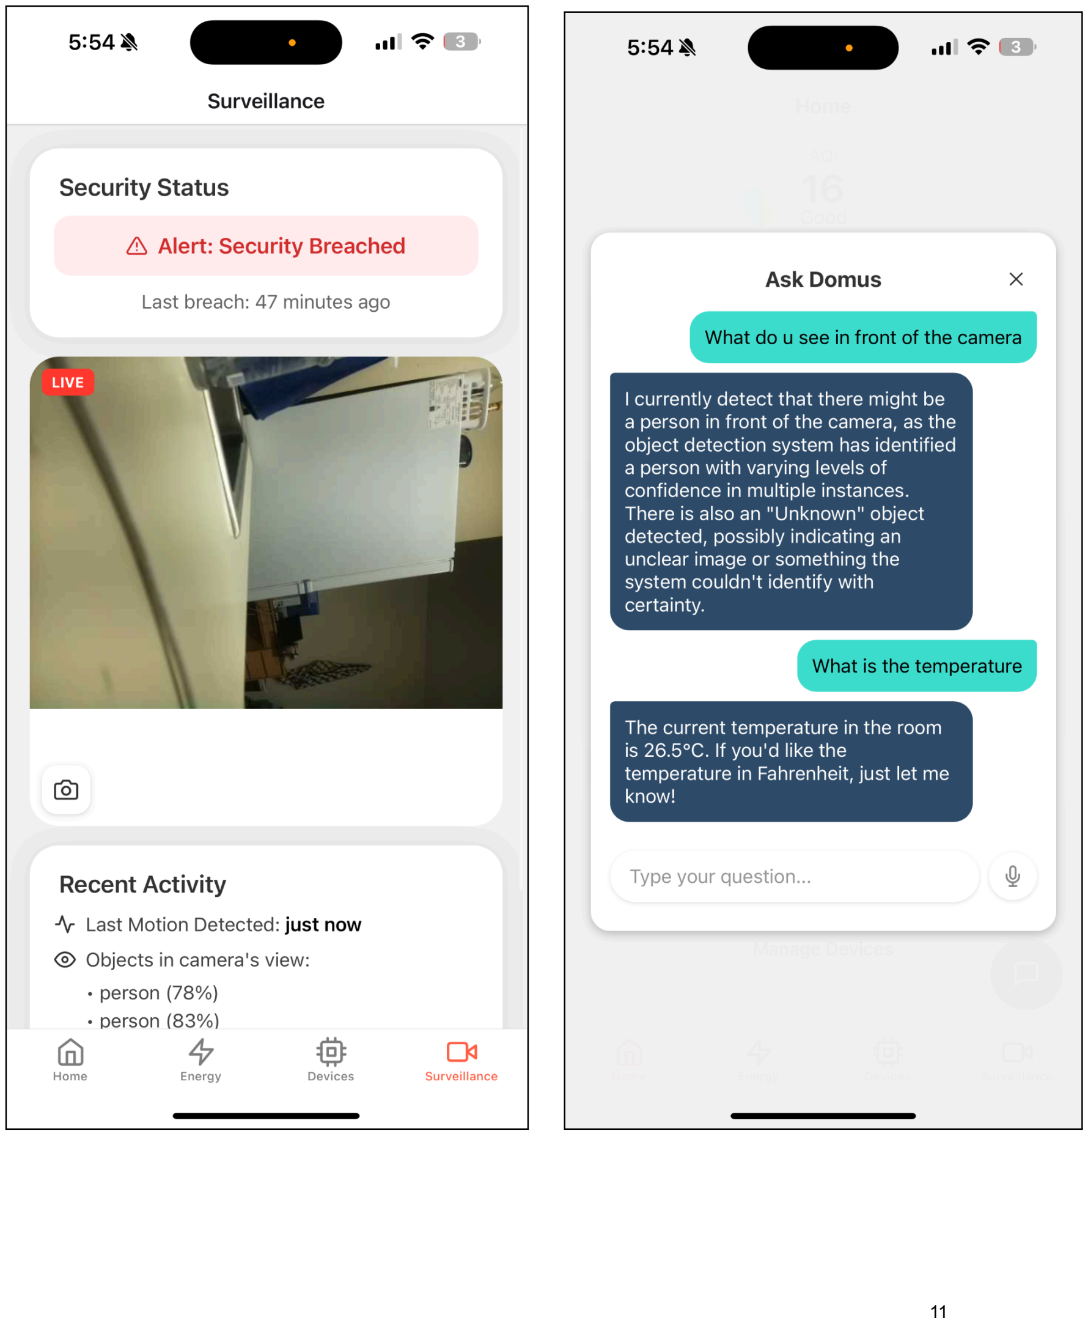
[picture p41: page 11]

11

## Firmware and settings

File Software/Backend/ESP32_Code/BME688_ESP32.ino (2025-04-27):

#include <WiFi.h>
#include <HTTPClient.h>
#include <Wire.h>
#include <Adafruit_Sensor.h>
#include "Adafruit_BME680.h"
#include <WebServer.h>
#include <Preferences.h>
#include <ESPmDNS.h>  // mDNS support

// BME680 sensor pins
#define BME_SDA 21
#define BME_SCL 22

Adafruit_BME680 bme;

// Replace these URLs with your actual backend endpoints:
const char* sensorServer = "http://domus-central.local:5000/bme688-latest";
const char* checkinServer = "http://domus-central.local:5000/device-checkin";  // Use your backend's checkin endpoint

// Web server for AP mode configuration
WebServer server(80);

// Preferences to store Wi-Fi credentials persistently
Preferences preferences;

// Global variables for credentials
String stored_ssid = "";
String stored_password = "";

// Generate HTML dropdown with available Wi-Fi networks
String getNetworkListHTML() {
  String html = "<select name='ssid'>";
  int n = WiFi.scanNetworks();
  if (n == 0) {
    html += "<option>No networks found</option>";
  } else {
    for (int i = 0; i < n; i++) {
      html += "<option value='" + WiFi.SSID(i) + "'>" + WiFi.SSID(i) +
              " (" + String(WiFi.RSSI(i)) + " dBm)</option>";
    }
  }
  html += "</select>";
  return html;
}

// Root page: configuration form
void handleRoot() {
  String html = "<html><body>";
  html += "<h1>Configure Wi-Fi</h1>";
  html += "<form action='/setup' method='POST'>";
  html += "Select Wi-Fi: " + getNetworkListHTML() + "<br><br>";
  html += "Password: <input type='password' name='password'><br><br>";
  html += "<input type='submit' value='Connect'>";
  html += "</form>";
  html += "</body></html>";
  server.send(200, "text/html", html);
}

// Handle form submission: store credentials and reboot
void handleSetup() {
  if (server.hasArg("ssid") && server.hasArg("password")) {
    stored_ssid = server.arg("ssid");
    stored_password = server.arg("password");

    preferences.begin("wifi", false);
    preferences.putString("ssid", stored_ssid);
    preferences.putString("pass", stored_password);
    preferences.end();

    String response = "Received credentials for SSID: " + stored_ssid +
                      ". The device will now attempt to connect and reboot.";
    server.send(200, "text/plain", response);
    delay(2000);
    ESP.restart();
  } else {
    server.send(400, "text/plain", "Missing ssid or password");
  }
}

// Start AP mode for configuration
void startAPMode() {
  WiFi.mode(WIFI_AP);
  WiFi.softAP("Domus-TempSensor");
  Serial.println("Started SoftAP: Domus-TempSensor");

  server.on("/", handleRoot);
  server.on("/setup", HTTP_POST, handleSetup);
  server.begin();
  Serial.println("Web server started in AP mode.");
}

void setup() {
  Serial.begin(115200);
  Wire.begin(BME_SDA, BME_SCL);

  // Initialize the BME680 sensor
  if (!bme.begin()) {
    Serial.println("Could not find BME680 sensor. Check wiring!");
    while (1);
  }
  
  bme.setTemperatureOversampling(BME680_OS_8X);
  bme.setHumidityOversampling(BME680_OS_2X);
  bme.setPressureOversampling(BME680_OS_4X);
  bme.setIIRFilterSize(BME680_FILTER_SIZE_3);
  bme.setGasHeater(320, 150);

  // Load stored Wi-Fi credentials
  preferences.begin("wifi", true);
  stored_ssid = preferences.getString("ssid", "");
  stored_password = preferences.getString("pass", "");
  preferences.end();

  if (stored_ssid == "") {
    Serial.println("No Wi-Fi credentials found. Starting AP mode for configuration.");
    WiFi.mode(WIFI_STA);
    WiFi.disconnect();
    delay(100);
    WiFi.scanNetworks();  // scan networks for the config page dropdown
    startAPMode();
  } else {
    Serial.println("Stored Wi-Fi credentials found. Connecting to Wi-Fi: " + stored_ssid);
    WiFi.mode(WIFI_STA);
    WiFi.begin(stored_ssid.c_str(), stored_password.c_str());

    int attempts = 0;
    while (WiFi.status() != WL_CONNECTED && attempts < 30) {
      delay(500);
      Serial.print(".");
      attempts++;
    }

    if (WiFi.status() == WL_CONNECTED) {
      Serial.println("\n✅ Connected to Wi-Fi");
      Serial.print("IP Address: ");
      Serial.println(WiFi.localIP());

      // Start mDNS responder with hostname "domus-device"
      if (MDNS.begin("domus-device")) {
        Serial.println("mDNS responder started: http://domus-device.local");
        MDNS.addService("domus", "tcp", 80);
      } else {
        Serial.println("❌ Failed to start mDNS");
      }
    } else {
      Serial.println("\n❌ Failed to connect to Wi-Fi");
      // Optionally, you can fall back to AP mode here.
    }
  }
}

void loop() {
  // In AP mode, handle configuration requests.
  if (stored_ssid == "") {
    server.handleClient();
    return;
  }

  // Send device check-in every 30 seconds
  static unsigned long lastCheckin = 0;
  unsigned long now = millis();
  if (now - lastCheckin >= 30000) {  // 30 seconds
    HTTPClient checkinHttp;
    Serial.print("Sending device checkin to: ");
    Serial.println(checkinServer);
    checkinHttp.begin(checkinServer);
    checkinHttp.addHeader("Content-Type", "application/json");
    // Use a unique identifier for your device.
    String checkinPayload = "{\"device_id\":\"Domus-TempSensor\"}";
    int checkinResponse = checkinHttp.POST(checkinPayload);
    Serial.print("Checkin Response Code: ");
    Serial.println(checkinResponse);
    checkinHttp.end();
    lastCheckin = now;
  }

  // Once connected, read sensor and POST sensor data every 10 seconds.
  if (WiFi.status() == WL_CONNECTED) {
    if (!bme.performReading()) {
      Serial.println("Sensor reading failed!");
      return;
    }

    String payload = "{\"temperature\":" + String(bme.temperature) +
                     ",\"humidity\":" + String(bme.humidity) +
                     ",\"pressure\":" + String(bme.pressure / 100.0) +
                     ",\"gas_resistance\":" + String(bme.gas_resistance / 1000.0) + "}";
    HTTPClient http;
    Serial.print("Sending sensor data POST to: ");
    Serial.println(sensorServer);

    http.begin(sensorServer);
    http.addHeader("Content-Type", "application/json");

    int response = http.POST(payload);
    if (response > 0) {
      Serial.print("✅ Sensor POST Response Code: ");
      Serial.println(response);
    } else {
      Serial.print("❌ Error Posting Sensor Data: ");
      Serial.println(response);
    }
    http.end();
  } else {
    Serial.println("🚫 Not connected to Wi-Fi");
  }

  delay(10000);  // Delay 10 seconds before next sensor reading
}

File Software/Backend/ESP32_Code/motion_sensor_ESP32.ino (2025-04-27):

#include <WiFi.h>
#include <HTTPClient.h>
#include <WebServer.h>
#include <Preferences.h>
#include <ESPmDNS.h>

#define PIR_PIN 27
WebServer server(80);
Preferences preferences;

String stored_ssid = "";
String stored_password = "";

const char* checkinServer = "http://domus-central.local:5000/device-checkin";
const char* motionServer = "http://domus-central.local:5000/motion-data";

// Generate Wi-Fi dropdown HTML
String getNetworkListHTML() {
  String html = "<select name='ssid'>";
  int n = WiFi.scanNetworks();
  for (int i = 0; i < n; i++) {
    html += "<option value='" + WiFi.SSID(i) + "'>" + WiFi.SSID(i) + "</option>";
  }
  html += "</select>";
  return html;
}

void handleRoot() {
  String html = "<html><body><h1>Configure Motion Sensor Wi-Fi</h1>";
  html += "<form action='/setup' method='POST'>";
  html += "Wi-Fi Network: " + getNetworkListHTML() + "<br><br>";
  html += "Password: <input type='password' name='password'><br><br>";
  html += "<input type='submit' value='Connect'>";
  html += "</form></body></html>";
  server.send(200, "text/html", html);
}

void handleSetup() {
  if (server.hasArg("ssid") && server.hasArg("password")) {
    stored_ssid = server.arg("ssid");
    stored_password = server.arg("password");

    preferences.begin("wifi", false);
    preferences.putString("ssid", stored_ssid);
    preferences.putString("pass", stored_password);
    preferences.end();

    server.send(200, "text/plain", "Received credentials. Rebooting...");
    delay(2000);
    ESP.restart();
  } else {
    server.send(400, "text/plain", "Missing ssid or password");
  }
}

void startAPMode() {
  WiFi.mode(WIFI_AP);
  WiFi.softAP("Domus-MotionSensor");
  Serial.println("Started SoftAP: Domus-MotionSensor");

  server.on("/", handleRoot);
  server.on("/setup", HTTP_POST, handleSetup);
  server.begin();
}

void setup() {
  Serial.begin(115200);
  pinMode(PIR_PIN, INPUT);

  preferences.begin("wifi", true);
  stored_ssid = preferences.getString("ssid", "");
  stored_password = preferences.getString("pass", "");
  preferences.end();

  if (stored_ssid == "") {
    Serial.println("No Wi-Fi credentials. Starting AP mode.");
    WiFi.disconnect();
    WiFi.scanNetworks();
    startAPMode();
  } else {
    WiFi.mode(WIFI_STA);
    WiFi.begin(stored_ssid.c_str(), stored_password.c_str());
    Serial.println("Connecting to Wi-Fi...");

    int attempts = 0;
    while (WiFi.status() != WL_CONNECTED && attempts < 30) {
      delay(500);
      Serial.print(".");
      attempts++;
    }

    if (WiFi.status() == WL_CONNECTED) {
      Serial.println("\n✅ Connected!");
      Serial.println(WiFi.localIP());

      if (MDNS.begin("domus-motion")) {
        Serial.println("mDNS started at http://domus-motion.local");
        MDNS.addService("http", "tcp", 80);
      }
    } else {
      Serial.println("❌ Failed to connect.");
    }
  }
}

void loop() {
  if (stored_ssid == "") {
    server.handleClient();
    return;
  }

  static unsigned long lastCheckin = 0;
  static int lastMotionState = LOW;

  unsigned long now = millis();

  if (now - lastCheckin > 30000) {
    if (WiFi.status() == WL_CONNECTED) {
      HTTPClient http;
      http.begin(checkinServer);
      http.addHeader("Content-Type", "application/json");
      http.POST("{\"device_id\": \"Domus-MotionSensor\"}");
      http.end();
      Serial.println("✅ Sent device check-in");
    }
    lastCheckin = now;
  }

  int currentMotion = digitalRead(PIR_PIN);
  if (currentMotion != lastMotionState && WiFi.status() == WL_CONNECTED) {
    HTTPClient http;
    http.begin(motionServer);
    http.addHeader("Content-Type", "application/json");

    String payload = currentMotion == HIGH ?
      "{\"motion\": \"detected\"}" : "{\"motion\": \"clear\"}";

    int response = http.POST(payload);
    Serial.print("Motion POST Response: ");
    Serial.println(response);
    http.end();
    lastMotionState = currentMotion;
  }

  delay(200);
}

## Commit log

2024-10-21 Test case for Motion sensor on rasberry pi
2024-10-30 Initial commit: Add home_query.py and sensor_data.json
2024-10-31 Add files via upload
    Code for the BME688 air quality sensor. Code writes records data to a csv file that will then be read by the LLM.
2024-10-31 Add files via upload
    Final code for HC-SR501 (motion sensor)
2024-11-09 Create BME688_code
    Run using Arduino IDE
2024-11-09 Create Motion_detection_final
    Change using Arduino IDE if needed
2024-11-27 Added SQL DB file and the updated sensor code
2024-11-30 modified sensor detection code with comments for readability
2024-12-02 Added the OpenAI LLM functionality by making changes to the App.js code to add it to the home screen, added the Chat button component by adding new component FloatingChatButton.js, and added the serv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
    Added the OpenAI LLM functionality by making changes to the App.js code to add it to the home screen, added the Chat button component by adding new component FloatingChatButton.js, and added the serv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
    Added the OpenAI LLM functionality by making changes to the App.js code to add it to the home screen, added the Chat button component by adding new component Float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
2025-04-27 Updated all READMEs, created Scipt files, updated all documentation, assets
    [BME688 BASE.STL, BME688 Housing.3mf, BME688 LID (1).STL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]
2025-04-28 Added housing models
    [BME688 LID (1).STL, BME688 LID.STL, camera_lid.STL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]
